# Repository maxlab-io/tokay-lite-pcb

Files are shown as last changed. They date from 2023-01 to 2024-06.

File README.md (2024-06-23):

# Tokay Lite: Low Power ESP32 Edge AI Camera (https://maxlab.io/store/edge-ai-camera/)

[Tokay Lite](https://maxlab.io/store/edge-ai-camera/) is the ESP32 camera development board ideal for low-power image
processing applications on the edge.

Tokay Lite can be used as standalone devkit to aid developers with a convinient
tool or be embedded in the bigger system to augument it with the vision and
image processing data.

## Tokay Lite Features

* ESP32-S3 chip compatible with TensorFlow Lite, enabling AI right in the device.
* OV2640 camera sensor delivering 15 fps @ 2MP.
* Ultra-low power design: programmable external RTC controls
  the entire power distribution, allowing the device to consume microamps during
  sleep.
* Motion detection with wake-up support.
* Nightvision mode with software-controlled IR filter to improve
  pictures during daytime.
* 10 IR LEDs to illuminate the scene.
* Ambient light sensor to intelligently select between day and night-time modes.
* Convenient 70mm x 70mm form factor.
* Embedded lithium battery charger and JST-PH battery connector.

## PCB Dimensions

Tokay LITE is packed into 70x70mm with M3 mounting holes at each corner,
as can be seen from a following drawing:

Tokay AI Camera dimensions

## Firmware

The Tokay AI Camera is powered by the ESP-IDF framework.

Check the [GitHub firmware repository]() for the source code
or [the camera documentation page](https://docs.maxlab.io/docs/edge-ai-tokay-lite/firmware/)
for more information on how to build an flash the firmware.

## KiCAD Dependencies

The Tokay PCB is made using [KiML](https://github.com/maxlab-io/kiml/),
the atomic components library from MAXLAB.

If you wish to modify the schematics or PCB you need to install KiML first.
Proceed to [the KiML installation guide](https://github.com/maxlab-io/kiml#how-to-install-kiml)
for further information.

## Ordering Samples

For information about ordering samples please proceed to [MAXLAB Tokay Lite product page](https://maxlab.io/store/edge-ai-camera/).

## License

The project is licensed under [the CERN Open Hardware Licence Version 2 - Permissive](./LICENSE.txt) terms.

## Business Inquiries or Questions

If you have the camera-related questions or inquiries, please drop us an email
on [hi@maxlab.io](mailto:hi@maxlab.io) or send us a message trough
[the Contact Us form](https://maxlab.io/contact/).

## Other Links

* [CADLAB.io](https://cadlab.io/project/27230). 
* [Hackaday](https://hackaday.io/project/189135-tokay-lite-multi-purpose-esp32-ai-camera)

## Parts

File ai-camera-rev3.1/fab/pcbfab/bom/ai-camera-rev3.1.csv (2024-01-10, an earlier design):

Item | Qty | Reference(s) | Value | LibPart | Footprint | Datasheet | DNP | DCR | LNK1 | LNK2 | MFR | MPN | Pmax | Rating | SNB1 | SNB2 | SPL1 | SPL2 | SPN1 | SPN2 | TCR | Tolerance | Type | UserValue
1 | 7 | C1, C11, C12, C25, C38, C39, C40 | 100u_CASE-B-3528_TAJB107K006RNJ | 00-kiml-capacitors-smd:100u_CASE-B-3528_TAJB107K006RNJ | 00-kiml-capacitor-tantalum:CP_EIA-3528-15_AVX-H | https://datasheet.lcsc.com/lcsc/2111161030_Kyocera-AVX-TAJB107K006RNJ-_C16133.pdf |  |  | https://jlcpcb.com/partdetail/KyoceraAvx-TAJB107K006RNJ/C16133 |  | Kyocera AVX | TAJB107K006RNJ |  | 6.3V | Basic Part |  | JLCPCB |  | C16133 |  |  | 10% |  | 100u
2 | 48 | C2, C3, C4, C5, C6, C7, C8, C9, C10, C13, C14, C15, C16, C18, C19, C20, C21, C22, C23, C24, C26, C27, C28, C29, C30, C31, C32, C33, C34, C35, C36, C37, C41, C42, C43, C44, C45, C46, C47, C49, C50, C51, C52, C53, C54, C55, C56, C57 | 10u_0402_CL05A105KA5NQNC | 00-kiml-capacitors-smd:1u_0402_CL05A105KA5NQNC | Capacitor_SMD:C_0402_1005Metric | https://datasheet.lcsc.com/lcsc/1811091611_Samsung-Electro-Mechanics-CL05A105KA5NQNC_C52923.pdf |  |  | https://jlcpcb.com/partdetail/53938-CL05A105KA5NQNC/C52923 |  | Samsung | CL05A105KA5NQNC |  | 25V | Basic Part |  | JLCPCB |  | C52923 |  |  | 10% |  | 1u
3 | 2 | C17, C48 | 22p_0402_0402CG220J500NT | 00-kiml-capacitors-smd:22p_0402_0402CG220J500NT | Capacitor_SMD:C_0402_1005Metric | https://datasheet.lcsc.com/lcsc/1811141710_FH--Guangdong-Fenghua-Advanced-Tech-0402CG220J500NT_C1555.pdf |  |  | https://jlcpcb.com/partdetail/1907-0402CG220J500NT/C1555 |  | FH | 0402CG220J500NT |  | 50V | Basic part |  | JLCPCB |  | C1555 |  |  | 5% | C0G | 22p
4 | 2 | D1, D7 | 0603_RED_KT-0603R | 00-kiml-led-smd:0603_RED_KT-0603R | LED_SMD:LED_0603_1608Metric | https://datasheet.lcsc.com/lcsc/1810231112_Hubei-KENTO-Elec-KT-0603R_C2286.pdf |  |  | https://jlcpcb.com/partdetail/Hubei_KentoElec-KT0603R/C2286 |  | Hubei KENTO | KT-0603R |  |  | Basic part |  | JLCPCB |  | C2286 |  |  |  |  | ~{CHRG}
5 | 1 | D2 | 0603_GREEN_19-217/GHC-YR1S2/3T | 00-kiml-led-smd:0603_GREEN_19-217/GHC-YR1S2/3T | LED_SMD:LED_0603_1608Metric |  |  |  | https://jlcpcb.com/partdetail/EverlightElec-19_217_GHC_YR1S23T/C72043 |  | Everlight | 19-217/GHC-YR1S2/3T |  |  | Basic part |  | JLCPCB |  | C72043 |  |  |  |  | ~{STDBY}
6 | 3 | D3, D4, D5 | SOD-523_BSD5C051L | 00-kiml-power-protection:SOD-523_BSD5C051L | Diode_SMD:D_SOD-523 | https://datasheet.lcsc.com/lcsc/1810161421_BORN-BSD5C051L_C151983.pdf |  |  | https://jlcpcb.com/partdetail/Born-BSD5C051L/C151983 |  | BORN | BSD5C051L |  |  | Extended Part |  | JLCPCB |  | C151983 |  |  |  |  | TVS 5V
7 | 2 | D6, D8 | B5819W-SL_SOD-123 | 00-kiml-diode:B5819W-SL_SOD-123 | Diode_SMD:D_SOD-123 | https://datasheet.lcsc.com/lcsc/1809140216_Jiangsu-Changjing-Electronics-Technology-Co---Ltd--B5819W-SL_C8598.pdf |  |  | https://jlcpcb.com/partdetail/9093-B5819WSL/C8598 |  | Jiangsu Changjing Electronics Technology | B5819W SL |  | 1A | Basic Part |  | JLCPCB |  | C8598 |  |  |  |  | D
8 | 10 | D9, D10, D11, D12, D13, D14, D15, D16, D17, D18 | 0603_IR_850nm_E6C0603IRAC1UDA | 00-kiml-led-smd:0603_IR_850nm_E6C0603IRAC1UDA | LED_SMD:LED_0603_1608Metric | https://datasheet.lcsc.com/lcsc/1912111437_EKINGLUX-E6C0603IRAC1UDA-850nm_C396643.pdf |  |  | https://jlcpcb.com/partdetail/Ekinglux-E6C0603IRAC1UDA_850nm/C396643 |  | EKINGLUX | E6C0603IRAC1UDA |  |  | Extended Part |  | JLCPCB |  | C396643 |  |  |  |  | LED_IR
9 | 4 | H1, H2, H3, H4 | MountingHole_Pad | Mechanical:MountingHole_Pad | MountingHole:MountingHole_3.2mm_M3_Pad_TopBottom | ~
10 | 1 | J1 | Conn-01x02_P2mm_NONAME_JST-PH_C47647 | 00-kiml-connector-jst:Conn-01x02_P2mm_NONAME_JST-PH_C47647 | 00-kiml-connector-jst:JST_PH_S2B-PH-SM4-TB_1x02-1MP_P2.00mm_Horizontal | https://datasheet.lcsc.com/lcsc/1912111436_BOOMELE-Boom-Precision-Elec-C47647_C47647.pdf |  |  | https://jlcpcb.com/partdetail/boomele_boom_Precision_elec-C47647/C47647 |  | BOOMELE | C47647 |  |  | Extended Part |  | JLCPCB |  | C47647 |  |  |  |  | BATT
11 | 1 | J2 | TYPE-C-31-M-12 | 00-kiml-connector-usb:USB_C_Receptacle_USB2.0_TYPE-C-31-M-12 | 00-kiml-connector-usb:USB_C_Receptacle_HRO_TYPE-C-31-M-12 | https://datasheet.lcsc.com/lcsc/2205251630_Korean-Hroparts-Elec-TYPE-C-31-M-12_C165948.pdf |  |  | https://jlcpcb.com/partdetail/Korean_HropartsElec-TYPE_C_31_M12/C165948 |  | Korean Hroparts | TYPE-C-31-M-12 |  |  | Extended Part |  | JLCPCB |  | C165948 |  |  |  |  | USB-C
12 | 1 | J4 | Conn-02x10_P2.54mm_B-2100S20P-B110 | 00-kiml-connector:Conn-02x10_P2.54mm_B-2100S20P-B110 | Connector_PinHeader_2.54mm:PinHeader_2x10_P2.54mm_Vertical | https://datasheet.lcsc.com/lcsc/1810241611_Ckmtw-Shenzhen-Cankemeng-B-2100S20P-B110_C124359.pdf |  |  | https://jlcpcb.com/partdetail/125634-B_2100S20PB110/C124359 |  | Ckmtw | B-2100S20P-B110 |  |  |  |  | JLCPCB |  | C124359 |  |  |  |  | USR_EXT
13 | 1 | J5 | Conn-01x02_P1.25mm_10114829-10102LF | 00-kiml-connector:Conn-01x02_P1.25mm_10114829-10102LF | 00-kiml-connector-amphenol:10114829-10102LF | https://datasheet.lcsc.com/lcsc/1811011512_Amphenol-ICC-10114829-10102LF_C239062.pdf |  |  | https://www.digikey.com/en/products/detail/amphenol-icc-fci/10114829-10102LF/2658929 | https://jlcpcb.com/partdetail/AmphenolIcc-1011482910102LF/C239062 | Amphenol ICC (FCI) | 10114829-10102LF |  |  |  | Extended Part | Digikey | JLCPCB | 609-4383-2-ND | C239062 |  |  |  | IRCUT
14 | 1 | J6 | Conn_01x24_FFC_0.5mm_AFC01-S24FCC-00 | 00-kiml-connector-fpc-ffc:Conn_01x24_FFC_0.5mm_AFC01-S24FCC-00 | 00-kiml-connector-fpc-ffc:Jushuo_AFC01-S24FCC-00_1x24-1MP_P0.50_Horizontal | https://datasheet.lcsc.com/lcsc/1811021338_JUSHUO-AFC01-S24FCC-00_C262276.pdf |  |  | https://jlcpcb.com/partdetail/Jushuo-AFC01_S24FCC00/C262276 |  | JUSHUO | AFC01-S24FCC-00 |  |  | Extended Part |  | JLCPCB |  | C262276 |  |  |  |  | CAMERA
15 | 1 | JP1 | USB_PWR | Jumper:SolderJumper_2_Bridged | Jumper:SolderJumper-2_P1.3mm_Bridged2Bar_Pad1.0x1.5mm | ~
16 | 1 | JP2 | PIR | Jumper:SolderJumper_2_Bridged | Jumper:SolderJumper-2_P1.3mm_Bridged2Bar_Pad1.0x1.5mm | ~
17 | 3 | L1, L2, L4 | FB_2A_0805_220R@100MHz_BLM21PG221SN1D | 00-kiml-inductors:FB_2A_0805_220R@100MHz_BLM21PG221SN1D | Inductor_SMD:L_0805_2012Metric_Pad1.15x1.40mm_HandSolder | ~ |  |  | https://jlcpcb.com/partdetail/MurataElectronics-BLM21PG221SN1D/C85840 |  | Murata Electronics | BLM21PG221SN1D |  | 2A |  |  | JLCPCB |  | C85840 |  |  |  |  | FB
18 | 2 | L3, L5 | 10u_1.5A_4x4mm_SWPA4030S100MT | 00-kiml-inductors:10u_1.5A_4x4mm_SWPA4030S100MT | 00-kiml-inductor-smd:L_Sunlord_SWPA40xxS | https://datasheet.lcsc.com/lcsc/2110091630_Sunlord-SWPA4030S100MT_C38117.pdf |  | 130m | https://jlcpcb.com/partdetail/Sunlord-SWPA4030S100MT/C38117 |  | Sunlord | SWPA4030S100MT |  | 1.5A |  |  | JLCPCB |  | C38117 |  |  |  |  | 10u
19 | 6 | Q1, Q2, Q5, Q7, Q9, Q10 | 2N7002 | 00-kiml-transistor-fet:2N7002 | Package_TO_SOT_SMD:SOT-23 | https://datasheet.lcsc.com/lcsc/1810151612_Jiangsu-Changjing-Electronics-Technology-Co---Ltd--2N7002_C8545.pdf |  |  | https://jlcpcb.com/partdetail/9040-2N7002/C8545 |  | JCET | 2N7002 |  |  | Basic Part |  | JLCPCB |  | C8545 |  |  |  |  | 2N7002
20 | 4 | Q3, Q4, Q6, Q8 | AO3401A | 00-kiml-transistor-fet:AO3401A | Package_TO_SOT_SMD:SOT-23 | https://datasheet.lcsc.com/lcsc/1810171817_Alpha---Omega-Semicon-AO3401A_C15127.pdf |  |  | https://lcsc.com/product-detail/MOSFETs_Alpha-Omega-Semicon-AO3401A_C15127.html | https://jlcpcb.com/partdetail/Alpha_OmegaSemicon-AO3401A/C15127 | Alpha & Omega Semiconductor Inc. | AO3401A |  |  |  | Basic Part | LCSC | JLCPCB | C15127 | C15127 |  |  |  | AO3401A
21 | 3 | R1, R2, R23 | 976k_0402_0402WGD9763TCE | 00-kiml-resistors-smd:976k_0402_0402WGD9763TCE | Resistor_SMD:R_0402_1005Metric | https://datasheet.lcsc.com/lcsc/2205312216_UNI-ROYAL-Uniroyal-Elec-0402WGD9763TCE_C423262.pdf |  |  | https://jlcpcb.com/partdetail/416212-0402WGD9763TCE/C423262 |  | UNI-ROYAL | 0402WGD9763TCE |  |  | Extended Part |  | JLCPCB |  | C423262 |  |  | 0.5% |  | 976k
22 | 13 | R3, R13, R15, R16, R17, R18, R19, R21, R22, R24, R25, R31, R32 | 215k_0402_0402WGD2153TCE | 00-kiml-resistors-smd:215k_0402_0402WGD2153TCE | Resistor_SMD:R_0402_1005Metric | https://datasheet.lcsc.com/lcsc/2205312216_UNI-ROYAL-Uniroyal-Elec-0402WGD2153TCE_C423299.pdf |  |  | https://jlcpcb.com/partdetail/416249-0402WGD2153TCE/C423299 |  | UNI-ROYAL | 0402WGD2153TCE |  |  | Extended Part |  | JLCPCB |  | C423299 |  |  | 0.5% |  | 215k
23 | 3 | R4, R5, R28 | 1k_0402_0402WGF1001TCE | 00-kiml-resistors-smd:1k_0402_0402WGF1001TCE | Resistor_SMD:R_0402_1005Metric | https://datasheet.lcsc.com/lcsc/2206010216_UNI-ROYAL-Uniroyal-Elec-0402WGF1001TCE_C11702.pdf |  |  | https://jlcpcb.com/partdetail/12256-0402WGF1001TCE/C11702 |  | UNI-ROYAL | 0402WGF1001TCE | 62.5mW |  | Basic part |  | JLCPCB |  | C11702 |  |  | 1% |  | 1k
24 | 11 | R6, R7, R10, R11, R12, R14, R20, R26, R27, R29, R30 | 10k_0402_0402WGF1002TCE | 00-kiml-resistors-smd:10k_0402_0402WGF1002TCE | Resistor_SMD:R_0402_1005Metric | https://datasheet.lcsc.com/lcsc/2206010100_UNI-ROYAL-Uniroyal-Elec-0402WGF1002TCE_C25744.pdf |  |  | https://jlcpcb.com/partdetail/26487-0402WGF1002TCE/C25744 |  | UNI-ROYAL | 0402WGF1002TCE | 62.5mW |  | Basic part |  | JLCPCB |  | C25744 |  | 100ppm | 1% |  | 10k
25 | 2 | R8, R9 | 5.1k_0603_0603WAF5101T5E | 00-kiml-resistors-smd:5.1k_0603_0603WAF5101T5E | Resistor_SMD:R_0603_1608Metric | https://datasheet.lcsc.com/lcsc/2206010116_UNI-ROYAL-Uniroyal-Elec-0603WAF5101T5E_C23186.pdf |  |  | https://jlcpcb.com/partdetail/23913-0603WAF5101T5E/C23186 |  | UNI-ROYAL | 0603WAF5101T5E |  |  | Basic Part |  | JLCPCB |  | C23186 |  |  | 1% |  | 5.1k
26 | 1 | R33 | 2.43R_0805_0805W8F243KT5E | 00-kiml-resistors-smd:2.43R_0805_0805W8F243KT5E | Resistor_SMD:R_0805_2012Metric | https://datasheet.lcsc.com/lcsc/2205311916_UNI-ROYAL-Uniroyal-Elec-0805W8F243KT5E_C247100.pdf |  |  | https://jlcpcb.com/partdetail/244308-0805W8F243KT5E/C247100 |  | UNI-ROYAL | 0805W8F243KT5E |  |  | Extended Part |  | JLCPCB |  | C247100 |  |  | 1% |  | 2.43R
27 | 2 | SW1, SW4 | SW_PB_90deg_K2-1102AQ-H4CW-01 | 00-kiml-switch-button-tht:SW_PB_90deg_K2-1102AQ-N4CW-01 | 00-kiml-switch-button-tht:SW_PB_90deg_K2-1102AQ-H4CW-01 | https://datasheet.lcsc.com/lcsc/2012052036_Korean-Hroparts-Elec-K2-1102AQ-H4CW-01_C961738.pdf |  |  | https://jlcpcb.com/partdetail/1041843-K2_1102AQ_H4CW01/C961738 |  | Korean Hroparts | K2-1102AQ-N4CW-01 |  |  | Extended Part |  | JLCPCB |  | C338650 |  |  |  |  | PWR_ON
28 | 2 | SW2, SW3 | SW_PB_TS-1187A-B-A-B | 00-kiml-switch-button-smd:SW_PB_TS-1187A-B-A-B | Button_Switch_SMD:SW_SPST_TL3342 | https://datasheet.lcsc.com/lcsc/2002271431_XKB-Connectivity-TS-1187A-B-A-B_C318884.pdf |  |  | https://jlcpcb.com/partdetail/XkbConnectivity-TS_1187A_B_AB/C318884 |  | XKB Connectivity | TS-1187A-B-A-B |  |  | Basic Part |  | JLCPCB |  | C318884 |  |  |  |  | BOOT
29 | 24 | TP1, TP2, TP3, TP4, TP5, TP6, TP7, TP8, TP9, TP10, TP11, TP12, TP13, TP14, TP15, TP16, TP17, TP18, TP19, TP20, TP21, TP22, TP23, TP24 | TestPoint | Connector:TestPoint | TestPoint:TestPoint_Pad_D1.0mm | ~
30 | 1 | U1 | TP4057-42-SOT26-R | 00-kiml-battery-management:TP4057-42-SOT26-R | Package_TO_SOT_SMD:SOT-23-6 | https://datasheet.lcsc.com/lcsc/1811021622_TOPPOWER-Nanjing-Extension-Microelectronics-TP4057-42-SOT26-R_C12044.pdf |  |  | https://jlcpcb.com/partdetail/12599-TP4057_42_SOT26R/C12044 |  | TOPPOWER | TP4057-42-SOT26-R |  |  | Basic Part |  | JLCPCB |  | C12044 |  |  |  |  | TP4057
31 | 2 | U2, U7 | XC6206-2.8V | 00-kiml-regulator-linear:XC6206-2.8V | Package_TO_SOT_SMD:SOT-23 | https://datasheet.lcsc.com/lcsc/2109071530_YONGYUTAI-XC6206-2-8V_C2892669.pdf |  |  | https://jlcpcb.com/partdetail/Yongyutai-XC6206_28V/C2892669 |  | YONGYUTAI | XC6206-2.8V |  |  | Extended Part |  | JLCPCB |  | C2892669 |  |  |  |  | XC6206-2.8V
32 | 1 | U3 | PCF85063AT | 00-kiml-timer-rtc:PCF85063AT/AAZ | Package_SO:SO-8_3.9x4.9mm_P1.27mm | https://www.nxp.com/docs/en/data-sheet/PCF85063A.pdf |  |  | https://jlcpcb.com/partdetail/NxpSemicon-PCF85063ATAAZ/C2157792 |  | NXP Semiconductors | PCF85063AT/AAZ |  |  | Extended Part |  | JLCPCB |  | C2157792 |  |  |  |  | PCF85063A
33 | 1 | U4 | TI_SN74LVC1G373DBVR | 00-kiml-74xGxx:TI_SN74LVC1G373DBVR | Package_TO_SOT_SMD:SOT-23-6 | https://www.ti.com/cn/lit/ds/symlink/sn74lvc1g373.pdf |  |  | https://jlcpcb.com/partdetail/TexasInstruments-SN74LVC1G373DBVR/C128413 |  | Texas Instruments | SN74LVC1G373DBVR |  |  | Extended Part |  | JLCPCB |  | C128413 |  |  |  |  | D-LATCH
34 | 1 | U5 | SY8089AAAC | 00-kiml-regulator-switching:SY8089AAAC | Package_TO_SOT_SMD:SOT-23-5 | https://datasheet.lcsc.com/lcsc/2108261630_Silergy-Corp-SY8089AAAC_C78988.pdf |  |  | https://jlcpcb.com/partdetail/SilergyCorp-SY8089AAAC/C78988 |  | Silergy | SY8089AAAC |  |  | Extended Part |  | JLCPCB |  | C78988 |  |  |  |  | SY8089AAAC
35 | 1 | U6 | PIR_AS312 | 00-kiml-optical:PIR_AS312 | 00-kiml-optical:AS312 | https://datasheet.lcsc.com/lcsc/2004261131_Senba-Sensing-Tech-AS312_C90465.pdf |  |  | https://jlcpcb.com/partdetail/Senba_SensingTech-AS312/C90465 |  | Senba Sensing | AS312 |  |  | Extended Part |  | JLCPCB |  | C90465 |  |  |  |  | AS312
36 | 1 | U8 | RT9166-12GVL | 00-kiml-regulator-linear:RT9166-12GVL | Package_TO_SOT_SMD:SOT-23 | https://datasheet.lcsc.com/lcsc/1810312311_Richtek-Tech-RT9166-12GVL_C29175.pdf |  |  | https://jlcpcb.com/partdetail/RichtekTech-RT916612GVL/C29175 |  | Richtek Tech | RT9166-12GVL |  |  | Extended Part |  | JLCPCB |  | C29175 |  |  |  |  | RT9166-12GVL
37 | 1 | U9 | AP1511B | 00-kiml-ircut-driver:AP1511B | Package_TO_SOT_SMD:SOT-23-6 | https://datasheet.lcsc.com/lcsc/2208021730_UMW-Youtai-Semiconductor-Co---Ltd--AP1511B_C347457.pdf |  |  | https://lcsc.com/product-detail/Motor-Driver-ICs_UMW-Youtai-Semiconductor-Co-Ltd-AP1511B_C347457.html | https://jlcpcb.com/partdetail/324117-AP1511B/C347457 | UMW | AP1511B |  |  |  | Extended Part | LCSC | JLCPCB | C347457 | C347457 |  |  |  | AP1511B
38 | 1 | U10 | ESP32-S3-WROOM-1-N16R8 | 00-kiml-rf-module:ESP32-S3-WROOM-1-N16R8 | 00-kiml-rf-module:ESP32-S3-WROOM-1 | https://www.espressif.com/sites/default/files/documentation/esp32-s3-wroom-1_wroom-1u_datasheet_en.pdf |  |  | https://www.lcsc.com/product-detail/WiFi-Modules_Espressif-Systems-ESP32-S3-WROOM-1-N16R8_C2913202.html | https://jlcpcb.com/partdetail/3198300-ESP32_S3_WROOM_1N16R8/C2913202 | Espressif | ESP32-S3-WROOM-1-N16R8 |  |  |  | Extended part | LCSC | JLCPCB | C2913202 | C2913202 |  |  |  | ESP32-S3-WROOM-1
39 | 1 | U11 | MT9284-28J | 00-kiml-driver-led:MT9284-28J | Package_TO_SOT_SMD:SOT-23-6 | https://datasheet.lcsc.com/lcsc/1806041028_XI-AN-Aerosemi-Tech-MT9284-28J_C181780.pdf |  |  | https://jlcpcb.com/partdetail/xi_an_AerosemiTech-MT928428J/C181780 |  | AEROSEMI | MT9284-28J |  |  | Extended Part |  | JLCPCB |  | C181780 |  |  |  |  | MT9284-28J
40 | 1 | U12 | LTR-303ALS-01 | 00-kiml-optical:LTR-303ALS-01 | 00-kiml-optical:Lite-On_LTR-303ALS-01 | https://datasheet.lcsc.com/lcsc/1912111437_Lite-On-LTR-303ALS-01_C364577.pdf |  |  | https://www.lcsc.com/product-detail/Ambient-Light-Sensors_Lite-On-LTR-303ALS-01_C364577.html |  | Lite-On | LTR-303ALS-01 |  |  | Extended Part |  | JLCPCB |  | C364577 |  |  |  |  | LTR-303ALS-01
41 | 1 | Y1 | 32.768kHz_Q13FC1350000400 | 00-kiml-crystal:32.768kHz_Q13FC1350000400 | 00-kiml-crystal-smd:Crystal_SMD_3215-2Pin_3.2x1.5mm | https://datasheet.lcsc.com/lcsc/1810171817_Seiko-Epson-Q13FC1350000400_C32346.pdf |  |  | https://jlcpcb.com/partdetail/SeikoEpson-Q13FC1350000400/C32346 |  | Seiko Epson | Q13FC1350000400 |  |  | Basic Part |  | JLCPCB |  | C32346 |  |  |  |  | 32.768kHz

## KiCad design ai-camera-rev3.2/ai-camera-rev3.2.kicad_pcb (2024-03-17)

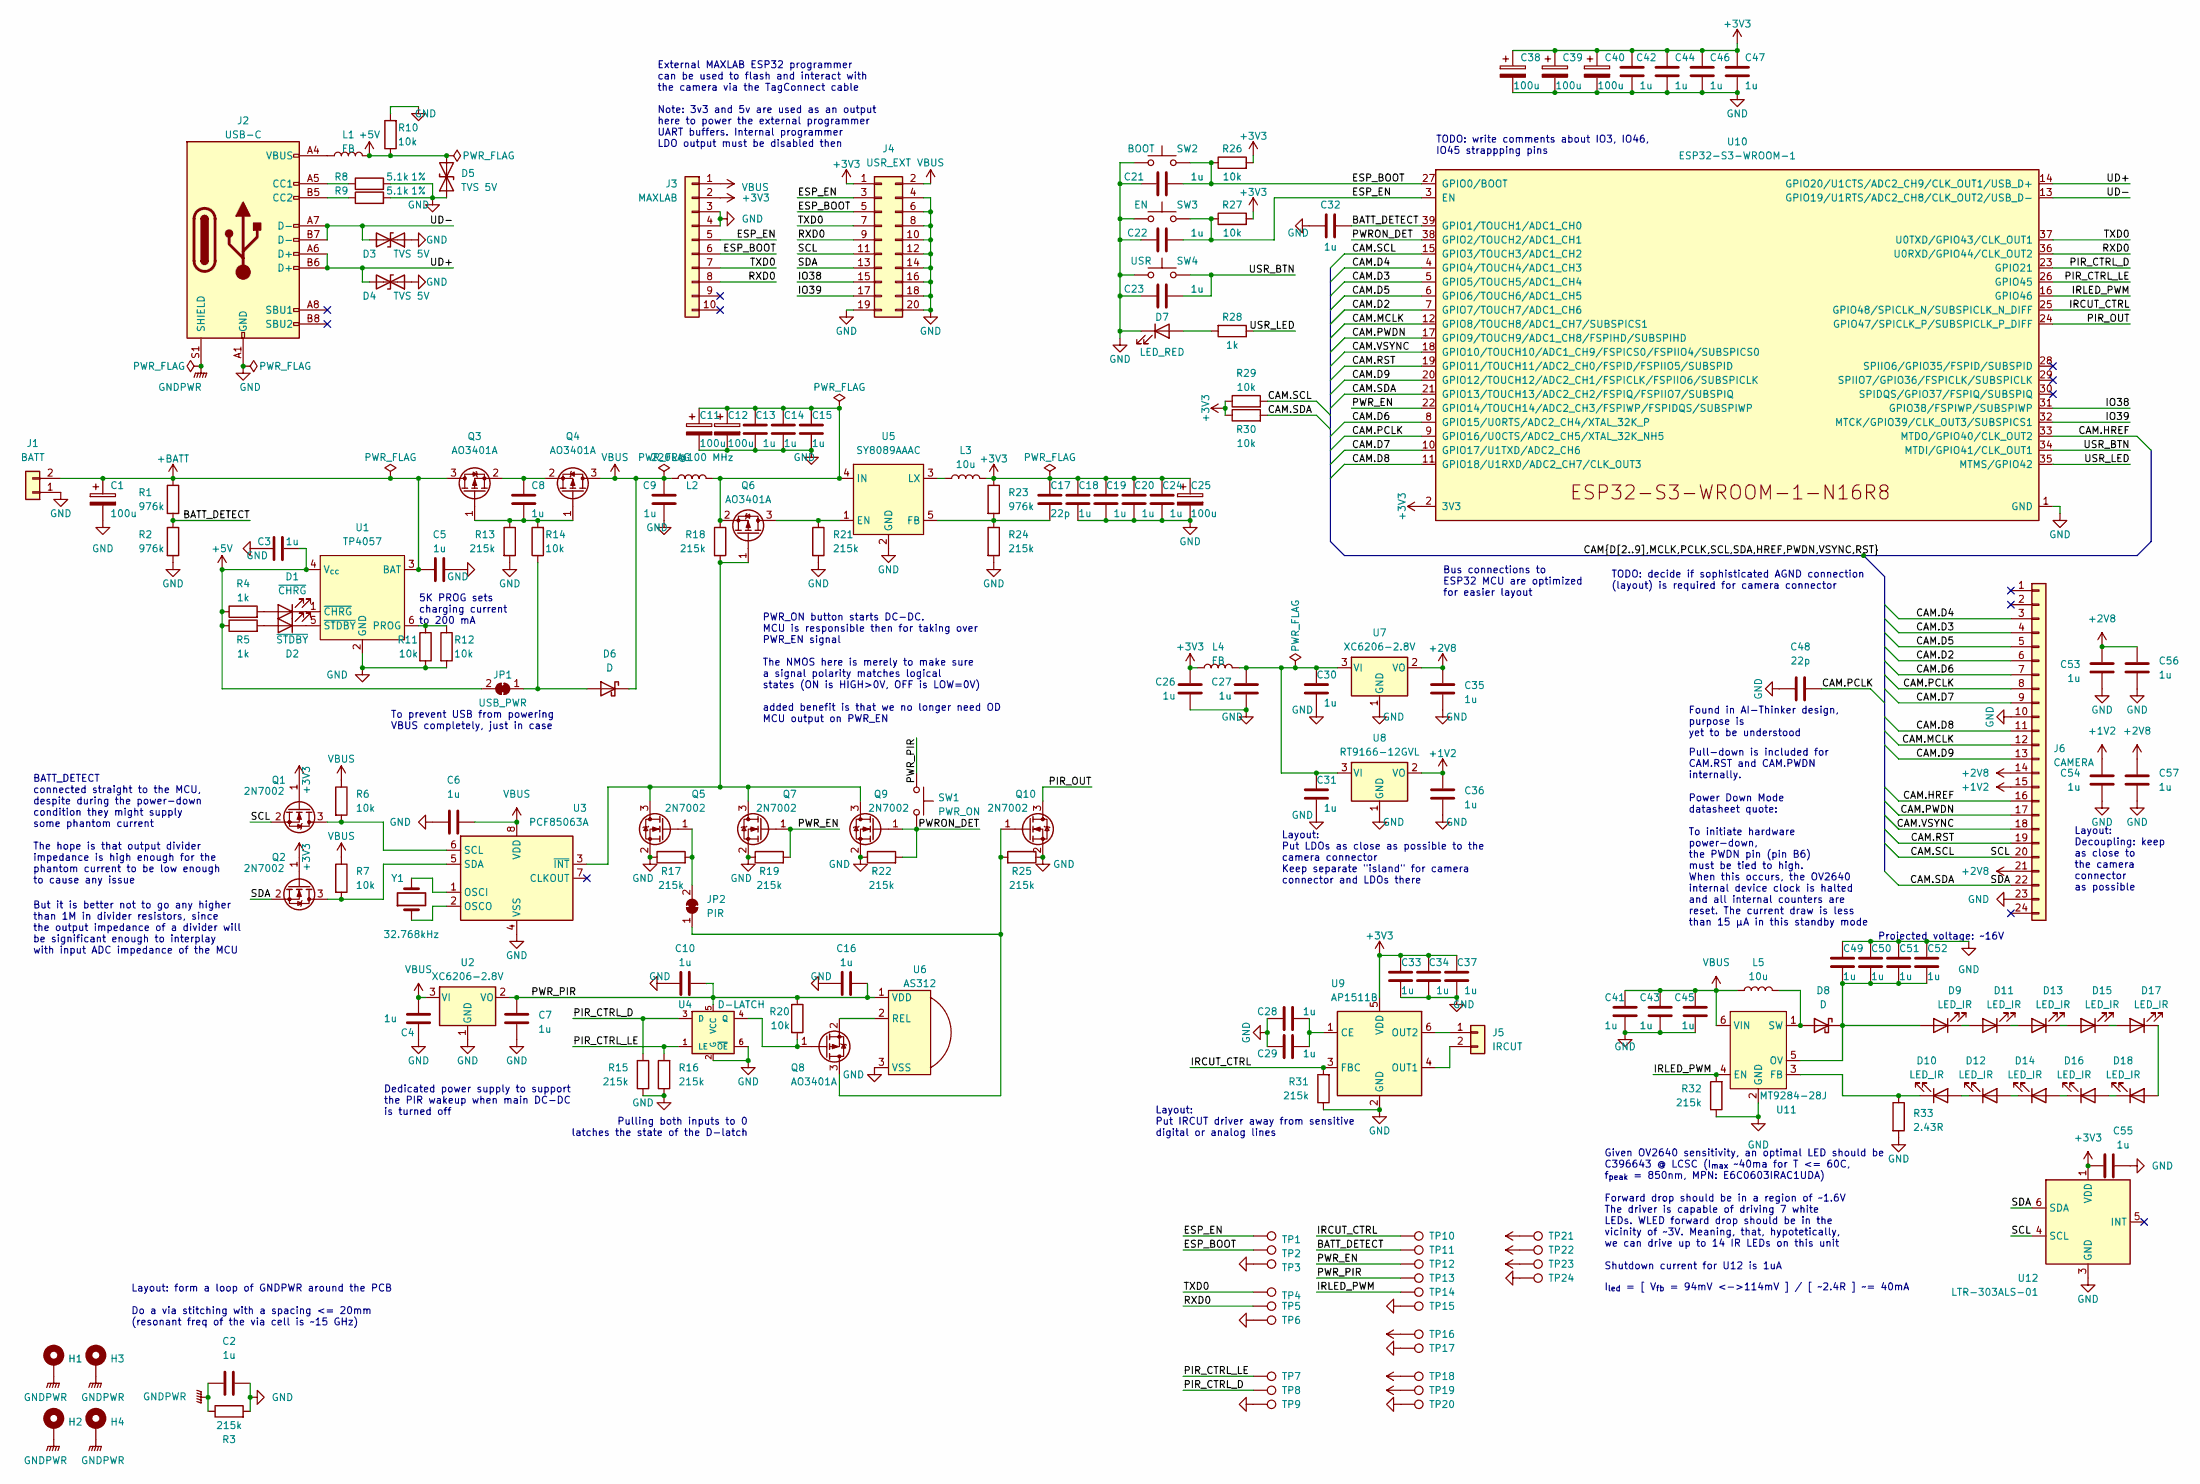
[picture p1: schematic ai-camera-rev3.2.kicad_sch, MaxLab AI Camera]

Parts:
C1, C11, C12, C25, C38, C39, C40: 100u_CASE-B-3528_TAJB107K006RNJ; CP_EIA-3528-15_AVX-H; Rating 6.3V; Tolerance 10%; MPN TAJB107K006RNJ
C2, C6, C10, C15, C16, C18, C21, C23, C28, C29, C32, C33, C45, C46, C47, C49, C54, C55, C56, C57: 10u_0402_CL05A105KA5NQNC; C_0402_1005Metric; Tolerance 10%; Rating 25V; MPN CL05A105KA5NQNC
C3, C4, C5, C7, C8, C9, C13, C14, C19, C20, C22, C24, C26, C27, C30, C31, C34, C35, C36, C37, C41, C42, C43, C44, C50, C51, C52, C53: 10u_0402_CL05A105KA5NQNC; C_0402_1005Metric; Rating 25V; Tolerance 10%; MPN CL05A105KA5NQNC
C17, C48: 22p_0402_0402CG220J500NT; C_0402_1005Metric; Rating 50V; Tolerance 5%; MPN 0402CG220J500NT
D1, D7: 0603_RED_KT-0603R; LED_0603_1608Metric; MPN KT-0603R
D2: 0603_GREEN_19-217/GHC-YR1S2/3T; LED_0603_1608Metric; MPN 19-217/GHC-YR1S2/3T
D3, D4, D5: SOD-523_BSD5C051L; D_SOD-523; MPN BSD5C051L
D6, D8: B5819W-SL_SOD-123; D_SOD-123; Rating 1A; MPN B5819W SL
D9, D10, D11, D12, D13, D14, D15, D16, D17, D18: 0603_IR_850nm_E6C0603IRAC1UDA; LED_0603_1608Metric; MPN E6C0603IRAC1UDA
H1, H2, H3, H4: MountingHole_Pad; MountingHole_3.2mm_M3_Pad_TopBottom
J1: Conn-01x02_P2mm_NONAME_JST-PH_C47647; JST_PH_S2B-PH-SM4-TB_1x02-1MP_P2.00mm_Horizontal; MPN C47647
J2: TYPE-C-31-M-12; USB_C_Receptacle_HRO_TYPE-C-31-M-12; MPN TYPE-C-31-M-12
J3: MAXLAB; Tag-Connect_TC2050-IDC-FP_2x05_P1.27mm_Vertical
J4: Conn-02x10_P2.54mm_B-2100S20P-B110; PinHeader_2x10_P2.54mm_Vertical; MPN B-2100S20P-B110
J5: Conn-01x02_P1.25mm_10114829-10102LF; 10114829-10102LF; MPN 10114829-10102LF
J6: Conn_01x24_FFC_0.5mm_AFC01-S24FCC-00; Jushuo_AFC01-S24FCC-00_1x24-1MP_P0.50_Horizontal; MPN AFC01-S24FCC-00
JP1: USB_PWR; SolderJumper-2_P1.3mm_Bridged2Bar_Pad1.0x1.5mm
JP2: PIR; SolderJumper-2_P1.3mm_Bridged2Bar_Pad1.0x1.5mm
L1, L2, L4: FB_2A_0805_220R@100MHz_BLM21PG221SN1D; L_0805_2012Metric_Pad1.15x1.40mm_HandSolder; Rating 2A; MPN BLM21PG221SN1D
L3, L5: 10u_1.5A_4x4mm_SWPA4030S100MT; L_Sunlord_SWPA40xxS; Rating 1.5A; MPN SWPA4030S100MT
Q1, Q2, Q5, Q7, Q9, Q10: 2N7002; SOT-23; MPN 2N7002
Q3, Q4, Q6, Q8: AO3401A; SOT-23; MPN AO3401A
R1, R2, R23: 976k_0402_0402WGD9763TCE; R_0402_1005Metric; Tolerance 0.5%; MPN 0402WGD9763TCE
R3, R13, R15, R16, R17, R18, R19, R21, R22, R24, R25, R31, R32: 215k_0402_0402WGD2153TCE; R_0402_1005Metric; Tolerance 0.5%; MPN 0402WGD2153TCE
R4, R5, R28: 1k_0402_0402WGF1001TCE; R_0402_1005Metric; Tolerance 1%; MPN 0402WGF1001TCE
R6, R7, R10, R11, R12, R14, R20, R26, R27, R29, R30: 10k_0402_0402WGF1002TCE; R_0402_1005Metric; Tolerance 1%; MPN 0402WGF1002TCE
R8, R9: 5.1k_0603_0603WAF5101T5E; R_0603_1608Metric; Tolerance 1%; MPN 0603WAF5101T5E
R33: 2.43R_0805_0805W8F243KT5E; R_0805_2012Metric; Tolerance 1%; MPN 0805W8F243KT5E
SW1, SW4: SW_PB_90deg_K2-1102AQ-H4CW-01; MPN K2-1102AQ-N4CW-01
SW2, SW3: SW_PB_TS-1187A-B-A-B; SW_SPST_TL3342; MPN TS-1187A-B-A-B
TP1, TP2, TP3, TP4, TP5, TP6, TP7, TP8, TP9, TP10, TP11, TP12, TP13, TP14, TP15, TP16, TP17, TP18, TP19, TP20, TP21, TP22, TP23, TP24: TestPoint; TestPoint_Pad_D1.0mm
U1: TP4057-42-SOT26-R; SOT-23-6; MPN TP4057-42-SOT26-R
U2, U7: XC6206-2.8V; SOT-23; MPN XC6206-2.8V
U3: PCF85063AT; SO-8_3.9x4.9mm_P1.27mm; MPN PCF85063AT/AAZ
U4: TI_SN74LVC1G373DBVR; SOT-23-6; MPN SN74LVC1G373DBVR
U5: SY8089AAAC; SOT-23-5; MPN SY8089AAAC
U6: PIR_AS312; AS312; MPN AS312
U8: RT9166-12GVL; SOT-23; MPN RT9166-12GVL
U9: AP1511B; SOT-23-6; MPN AP1511B
U10: ESP32-S3-WROOM-1-N16R8; ESP32-S3-WROOM-1; MPN ESP32-S3-WROOM-1-N16R8
U11: MT9284-28J; SOT-23-6; MPN MT9284-28J
U12: LTR-303ALS-01; Lite-On_LTR-303ALS-01; MPN LTR-303ALS-01
Y1: 32.768kHz_Q13FC1350000400; Crystal_SMD_3215-2Pin_3.2x1.5mm; MPN Q13FC1350000400

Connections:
+1V2: C36.1, C54.2, J6.15, TP16.1, U8.2 (VO)
+2V8: C35.1, C53.1, C56.2, C57.2, J6.14, J6.21, TP18.1, U7.2 (VO)
+3V3: C17.1, C18.2, C19.2, C20.2, C24.2, C25.1, C26.1, C33.2, C34.2, C37.2, C38.1, C39.1, C40.1, C42.1, C44.1, C46.1, C47.1, C55.1, J3.2, J4.1, L3.2, L4.1, Q1.1 (G), Q2.1 (G), R23.1, R26.2, R27.2, R29.1, R30.1, TP22.1, U9.5 (VDD), U10.2 (3V3), U12.1 (VDD)
+5V: C3.2, D5.2 (A2), JP1.2 (B), L1.2, R4.1, R5.1, R10.1, TP23.1, U1.4 (V_{cc})
+BATT: C1.1, C5.1, J1.2, Q3.3 (D), R1.1, TP19.1, U1.3 (BAT)
/BATT_DETECT: C32.1, R1.2, R2.1, TP11.1, U10.39 (GPIO1/TOUCH1/ADC1_CH0)
/CAM.D2: J6.6, U10.7 (GPIO7/TOUCH7/ADC1_CH6)
/CAM.D3: J6.4, U10.5 (GPIO5/TOUCH5/ADC1_CH4)
/CAM.D4: J6.3, U10.4 (GPIO4/TOUCH4/ADC1_CH3)
/CAM.D5: J6.5, U10.6 (GPIO6/TOUCH6/ADC1_CH5)
/CAM.D6: J6.7, U10.8 (GPIO15/U0RTS/ADC2_CH4/XTAL_32K_P)
/CAM.D7: J6.9, U10.10 (GPIO17/U1TXD/ADC2_CH6)
/CAM.D8: J6.11, U10.11 (GPIO18/U1RXD/ADC2_CH7/CLK_OUT3)
/CAM.D9: J6.13, U10.20 (GPIO12/TOUCH12/ADC2_CH1/FSPICLK/FSPIIO6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)
/CAM.HREF: J6.16, U10.33 (MTDO/GPIO40/CLK_OUT2)
/CAM.MCLK: J6.12, U10.12 (GPIO8/TOUCH8/ADC1_CH7/SUBSPICS1)
/CAM.PCLK: C48.1, J6.8, U10.9 (GPIO16/U0CTS/ADC2_CH5/XTAL_32K_NH5)
/CAM.PWDN: J6.17, U10.17 (GPIO9/TOUCH9/ADC1_CH8/FSPIHD/SUBSPIHD)
/CAM.RST: J6.19, U10.19 (GPIO11/TOUCH11/ADC2_CH0/FSPID/FSPIIO5/S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)
/CAM.SCL: J4.11, J6.20, Q1.2 (S), R29.2, U10.15 (GPIO3/TOUCH3/ADC1_CH2), U12.4 (SCL)
/CAM.SDA: J4.13, J6.22, Q2.2 (S), R30.2, U10.21 (GPIO13/TOUCH13/ADC2_CH2/FSPIQ/FSPIIO7/S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), U12.6 (SDA)
/CAM.VSYNC: J6.18, U10.18 (GPIO10/TOUCH10/ADC1_CH9/FSPICS0/FSPIIO4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)
/ESP_BOOT: C21.2, J3.6, J4.5, R26.1, SW2.2, TP2.1, U10.27 (GPIO0/BOOT)
/ESP_EN: C22.2, J3.5, J4.3, R27.1, SW3.2, TP1.1, U10.3 (EN)
/IO38: J4.15, U10.31 (GPIO38/FSPIWP/SUBSPIWP)
/IO39: J4.17, U10.32 (MTCK/GPIO39/CLK_OUT3/SUBSPICS1)
/IRCUT_CTRL: R31.2, TP10.1, U9.3 (FBC), U10.25 (GPIO48/SPICLK_N/SUBSPICLK_N_DIFF)
/IRLED_PWM: R32.2, TP14.1, U10.16 (GPIO46), U11.4 (EN)
/PIR_CTRL_D: R15.2, TP8.1, U4.3 (D), U10.23 (GPIO21)
/PIR_CTRL_LE: R16.2, TP7.1, U4.1 (LE), U10.26 (GPIO45)
/PIR_OUT: Q10.3 (D), U10.24 (GPIO47/SPICLK_P/SUBSPICLK_P_DIFF)
/PWRON_DET: Q9.1 (G), R22.2, SW1.2, U10.38 (GPIO2/TOUCH2/ADC1_CH1)
/PWR_EN: Q7.1 (G), R19.2, TP12.1, U10.22 (GPIO14/TOUCH14/ADC2_CH3/FSPIWP/FSPIDQS/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)
/PWR_PIR: C7.1, C10.1, C16.1, R20.1, SW1.1, TP13.1, U2.2 (VO), U4.5 (VCC), U6.1 (VDD)
/RXD0: J3.8, J4.9, TP5.1, U10.36 (U0RXD/GPIO44/CLK_OUT2)
/TXD0: J3.7, J4.7, TP4.1, U10.37 (U0TXD/GPIO43/CLK_OUT1)
/UD+: D4.2 (A2), J2.A6 (D+), J2.B6 (D+), U10.14 (GPIO20/U1CTS/ADC2_CH9/CLK_OUT1/USB_D+)
/UD-: D3.2 (A2), J2.A7 (D-), J2.B7 (D-), U10.13 (GPIO19/U1RTS/ADC2_CH8/CLK_OUT2/USB_D-)
/USR_BTN: C23.2, SW4.2, U10.34 (MTDI/GPIO41/CLK_OUT1)
/USR_LED: R28.1, U10.35 (MTMS/GPIO42)
GND: C1.2, C2.1, C3.1, C4.1, C5.2, C6.2, C7.2, C9.1, C10.2, C11.2, C12.2, C13.1, C14.2, C15.1, C16.2, C18.1, C19.1, C20.1, C21.1, C22.1, C23.1, C24.1, C25.2, C26.2, C27.2, C28.2, C29.2, C30.2, C31.2, C32.2, C33.1, C34.1, C35.2, C36.2, C37.1, C38.2, C39.2, C40.2, C41.1, C42.2, C43.2, C44.2, C45.1, C46.2, C47.2, C48.2, C49.2, C50.1, C51.1, C52.1, C53.2, C54.1, C55.2, C56.1, C57.1, D3.1 (A1), D4.1 (A1), D5.1 (A1), D7.1 (K), J1.1, J2.A1 (GND), J2.A12 (GND), J2.B1 (GND), J2.B12 (GND), J3.3, J3.4, J4.4, J4.6, J4.8, J4.10, J4.12, J4.14, J4.16, J4.18, J4.19, J4.20, J6.10, J6.23, Q5.2 (S), Q7.2 (S), Q9.2 (S), Q10.2 (S), R2.2, R3.2, R8.2, R9.2, R10.2, R11.2, R12.2, R13.2, R15.1, R16.1, R17.1, R19.1, R21.2, R22.1, R24.2, R25.1, R31.1, R32.1, R33.2, SW2.1, SW3.1, SW4.1, TP3.1, TP6.1, TP9.1, TP15.1, TP17.1, TP20.1, TP24.1, U1.2 (GND), U2.1 (GND), U3.4 (VSS), U4.2 (G), U4.6 (~OE), U5.2 (GND), U6.3 (VSS), U7.1 (GND), U8.1 (GND), U9.2 (GND), U10.1 (GND), U10.40 (GND), U10.41 (GND), U11.2 (GND), U12.3 (GND)
GNDPWR: C2.2, H1.1, H2.1, H3.1, H4.1, J2.S1 (SHIELD), R3.1
unnamed: D1.2 (A), R4.2
unnamed: D1.1 (K), U1.1 (~CHRG)
unnamed: D2.2 (A), R5.2
unnamed: D2.1 (K), U1.5 (~STDBY)
unnamed: D6.2 (A), JP1.1 (A), R14.1
unnamed: D7.2 (A), R28.2
unnamed: D8.2 (A), L5.2, U11.1 (SW)
unnamed: C49.1, C50.2, C51.2, C52.2, D8.1 (K), D9.2 (A), U11.5 (OV)
unnamed: D10.2 (A), D12.1 (K)
unnamed: D10.1 (K), R33.1, U11.3 (FB)
unnamed: D9.1 (K), D11.2 (A)
unnamed: D11.1 (K), D13.2 (A)
unnamed: D12.2 (A), D14.1 (K)
unnamed: D13.1 (K), D15.2 (A)
unnamed: D14.2 (A), D16.1 (K)
unnamed: D15.1 (K), D17.2 (A)
unnamed: D16.2 (A), D18.1 (K)
unnamed: D17.1 (K), D18.2 (A)
unnamed: J2.A5 (CC1), R8.1
unnamed: J2.B5 (CC2), R9.1
unnamed: J2.A4 (VBUS), J2.A9 (VBUS), J2.B4 (VBUS), J2.B9 (VBUS), L1.1
unnamed: J5.1, U9.6 (OUT2)
unnamed: J5.2, U9.4 (OUT1)
unnamed: JP2.1 (A), Q8.3 (D), Q10.1 (G), R25.2
unnamed: JP2.2 (B), Q5.1 (G), R17.2
unnamed: Q1.3 (D), R6.2, U3.6 (SCL)
unnamed: Q2.3 (D), R7.2, U3.5 (SDA)
unnamed: C8.1, Q3.1 (G), Q4.1 (G), R13.1, R14.2
unnamed: C8.2, Q3.2 (S), Q4.2 (S)
unnamed: Q5.3 (D), Q6.1 (G), Q7.3 (D), Q9.3 (D), R18.2, U3.3 (~INT)
unnamed: Q6.3 (D), R21.1, U5.1 (EN)
unnamed: C11.1, C12.1, C13.2, C14.1, C15.2, L2.2, Q6.2 (S), R18.1, U5.4 (IN)
unnamed: Q8.1 (G), R20.2, U4.4 (Q)
unnamed: Q8.2 (S), U6.2 (REL)
unnamed: R11.1, R12.1, U1.6 (PROG)
unnamed: U3.1 (OSCI), Y1.2
unnamed: U3.2 (OSCO), Y1.1
unnamed: C17.2, R23.2, R24.1, U5.5 (FB)
unnamed: L3.1, U5.3 (LX)
unnamed: C27.1, C30.1, C31.1, L4.2, U7.3 (VI), U8.3 (VI)
unnamed: C28.1, C29.1, U9.1 (CE)
VBUS: C4.2, C6.1, C9.2, C41.2, C43.1, C45.2, D6.1 (K), J3.1, J4.2, L2.1, L5.1, Q4.3 (D), R6.1, R7.1, TP21.1, U2.3 (VI), U3.8 (VDD), U11.6 (VIN)

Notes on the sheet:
Found in AI-Thinker design, purpose is yet to be understood
External MAXLAB ESP32 programmer can be used to flash and interact with the camera via the TagConnect cable
I_{led} = [ V_{fb} = 94mV <->114mV ] / [ ~2.4R ] ~= 40mA
But it is better not to go any higher than 1M in divider resistors, since the output impedance of a divider will be significant enough to interplay with input ADC impedance of the MCU
Pulling both inputs to 0 latches the state of the D-latch
Note: 3v3 and 5v are used as an output here to power the external programmer UART buffers. Internal programmer LDO output must be disabled then
Layout: Put IRCUT driver away from sensitive digital or analog lines
Layout: form a loop of GNDPWR around the PCB Do a via stitching with a spacing <= 20mm (resonant freq of the via cell is ~15 GHz)
Pull-down is included for CAM.RST and CAM.PWDN internally.
TODO: write comments about IO3, IO46, IO45 strappping pins
Bus connections to ESP32 MCU are optimized for easier layout
To prevent USB from powering VBUS completely, just in case
PWR_ON button starts DC-DC. MCU is responsible then for taking over PWR_EN signal The NMOS here is merely to make sure a signal polarity matches logical states (ON is HIGH>0V, OFF is LOW=0V) added benefit is that we no longer need OD MCU output on PWR_EN
Power Down Mode datasheet quote: To initiate hardware power-down, the PWDN pin (pin B6) must be tied to high. When this occurs, the OV2640 internal device clock is halted and all internal counters are reset. The current draw is less than 15 µA in this standby mode
Layout: Put LDOs as close as possible to the camera connector Keep separate "island" for camera connector and LDOs there
TODO: decide if sophisticated AGND connection (layout) is required for camera connector
5K PROG sets charging current to 200 mA
Given OV2640 sensitivity, an optimal LED should be C396643 @ LCSC (I_{max} ~40ma for T <= 60C, f_{peak} = 850nm, MPN: E6C0603IRAC1UDA) Forward drop should be in a region of ~1.6V The driver is capable of driving 7 white LEDs. WLED forward drop should be in the vicinity of ~3V. Meaning, that, hypote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
BATT_DETECT connected straight to the MCU, despite during the power-down condition they might supply some phantom current The hope is that output divider impedance is high enough for the phantom current to be low enough to cause any issue
Dedicated power supply to support the PIR wakeup when main DC-DC is turned off
Projected voltage: ~16V
Layout: Decoupling: keep as close to the camera connector as possible

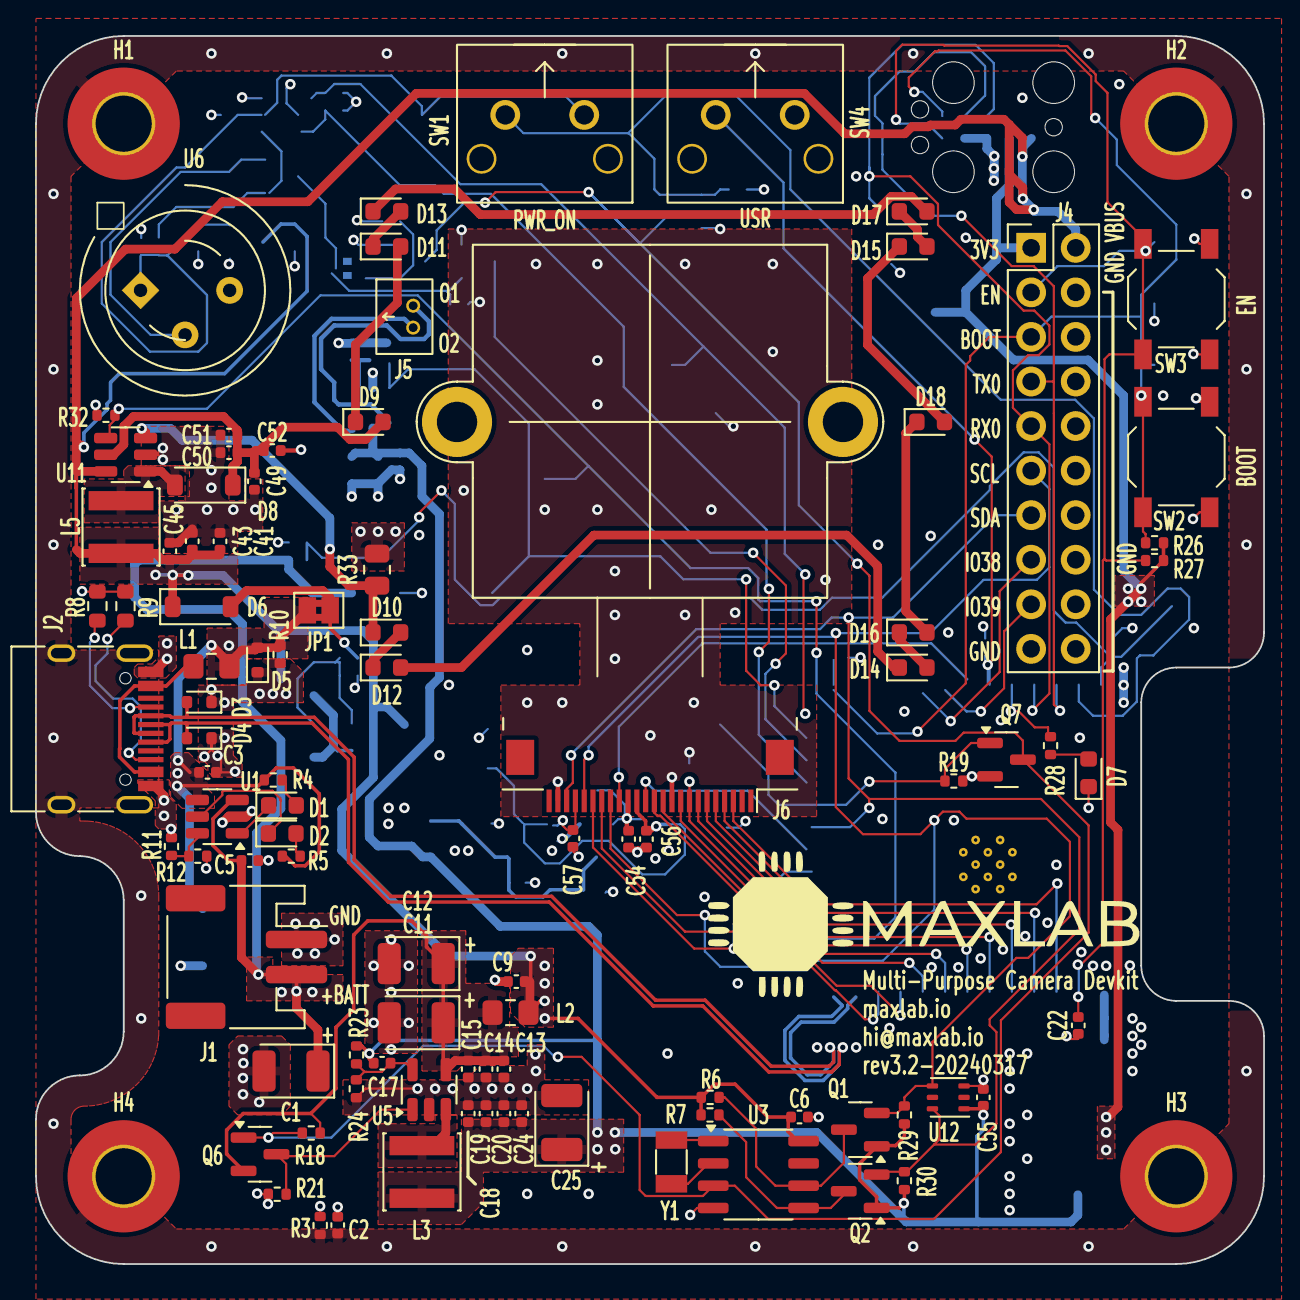
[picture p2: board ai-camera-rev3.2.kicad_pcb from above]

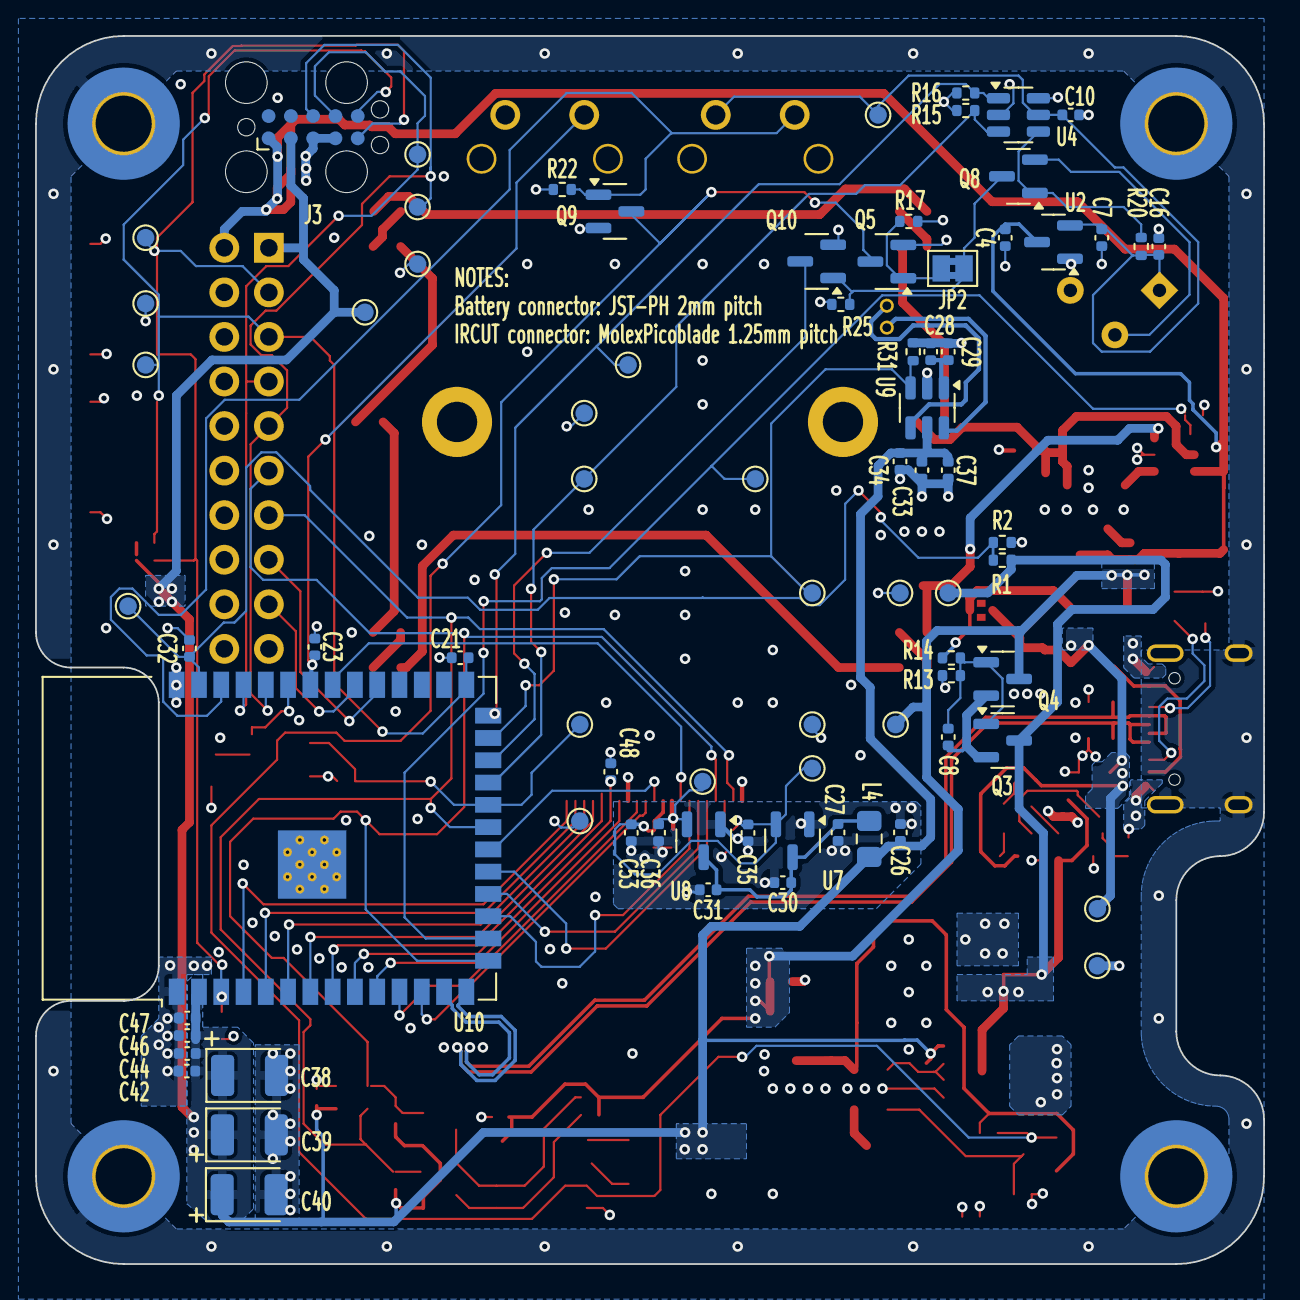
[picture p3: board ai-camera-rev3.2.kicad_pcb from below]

Board: 4 copper layers, 70.0 x 70.0 mm, 176 parts (78 on the bottom side), 84 nets.

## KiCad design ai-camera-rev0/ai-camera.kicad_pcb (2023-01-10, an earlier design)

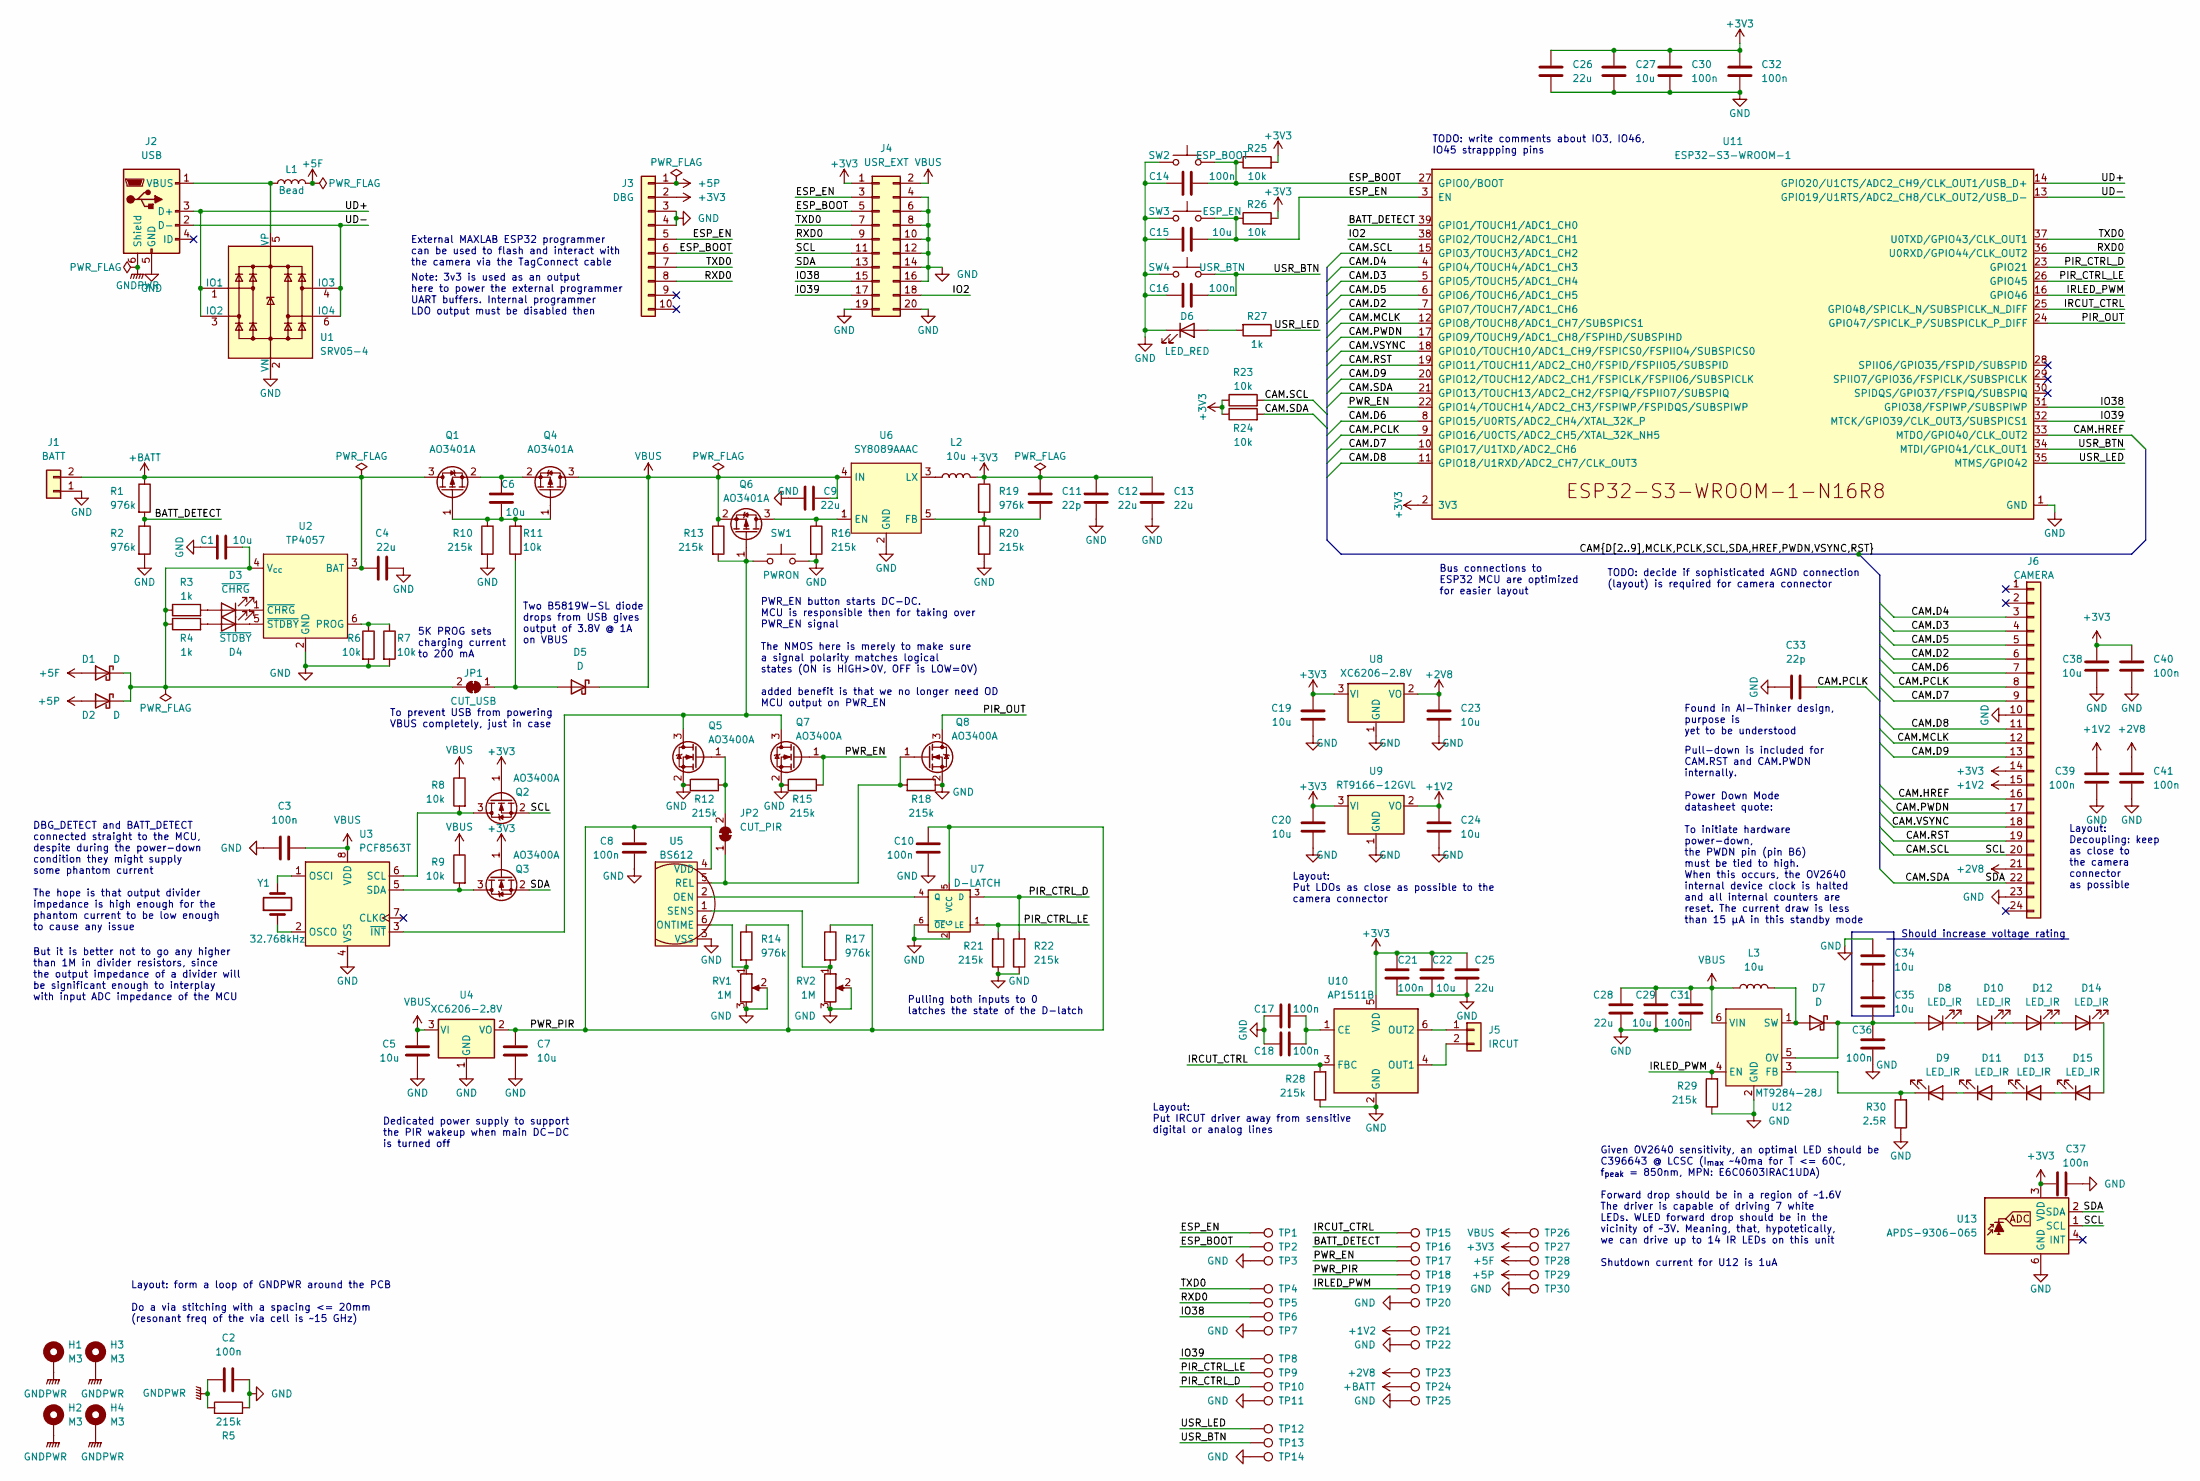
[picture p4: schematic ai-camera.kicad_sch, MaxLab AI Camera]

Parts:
C1, C5, C6, C7, C15, C19, C20, C22, C23, C24, C27, C29, C34, C35, C38: 10u_0603_CL10A106MA8NRNC; C_0603_1608Metric; Rating 25V; Tolerance 20%; MPN CL10A106MA8NRNC
C2, C3, C8, C10, C14, C16, C17, C18, C21, C30, C31, C32, C36, C37, C39, C40, C41: 100n_0402_CL05B104KB54PNC; C_0402_1005Metric; Tolerance 10%; Rating 50V; MPN CL05B104KB54PNC
C4, C9, C12, C13, C25, C26, C28: 22u_0805_CL21A226MAQNNNE; C_0805_2012Metric; Rating 10V; Tolerance 20%; MPN CL21A226MAQNNNE
C11, C33: 22p_0402_0402CG220J500NT; C_0402_1005Metric; Rating 50V; Tolerance 5%; MPN 0402CG220J500NT
D1, D2, D5, D7: B5819W-SL_SOD-123; D_SOD-123; MPN B5819W SL
D3, D6: 0603_RED_KT-0603R; LED_0603_1608Metric; MPN KT-0603R
D4: 0603_GREEN_19-217/GHC-YR1S2/3T; LED_0603_1608Metric; MPN 19-217/GHC-YR1S2/3T
D8, D9, D10, D11, D12, D13, D14, D15: 0603_IR_850nm_E6C0603IRAC1UDA; LED_0603_1608Metric; MPN E6C0603IRAC1UDA
H1, H2, H3, H4: M3; MountingHole_3.2mm_M3_DIN965_Pad_TopBottom
J1: Conn-01x02_P2mm_NONAME_JST-PH_C47647; JST_PH_S2B-PH-SM4-TB_1x02-1MP_P2.00mm_Horizontal; MPN C47647
J2: USB_B_Micro_10118194-0001LF; USB_Micro-B_Amphenol_10118194_Horizontal; MPN 10118194-0001LF
J3: DBG; Tag-Connect_TC2050-IDC-NL_2x05_P1.27mm_Vertical
J4: Conn-02x10_P2.54mm_B-2100S20P-B110; PinHeader_2x10_P2.54mm_Vertical; MPN B-2100S20P-B110
J5: Conn-01x02_P1.25mm_10114829-10102LF; 10114829-10102LF; MPN 10114829-10102LF
J6: Conn_01x24_FFC_0.5mm_hirose_FH12-24S-0.5SH; Hirose_FH12-24S-0.5SH_1x24-1MP_P0.50mm_Horizontal; MPN FH12-24S-0.5SH
JP1: CUT_USB; SolderJumper-2_P1.3mm_Bridged_RoundedPad1.0x1.5mm
JP2: CUT_PIR; SolderJumper-2_P1.3mm_Bridged_RoundedPad1.0x1.5mm
L1: 0805_FB_220R@100MHz_BLM21PG221SN1D; L_0805_2012Metric_Pad1.15x1.40mm_HandSolder; Rating 2A; MPN BLM21PG221SN1D
L2, L3: 10u_SWPA4030S100MT; L_Sunlord_SWPA40xxS; Rating 1.5A; MPN SWPA4030S100MT
Q1, Q4, Q6: AO3401A; SOT-23; MPN AO3401A
Q2, Q3, Q5, Q7, Q8: AO3400A; SOT-23; MPN AO3400A
R1, R2, R14, R17, R19: 976k_0402_0402WGD9763TCE; R_0402_1005Metric; Tolerance 0.5%; MPN 0402WGD9763TCE
R3, R4, R27: 1k_0402_0402WGF1001TCE; R_0402_1005Metric; Tolerance 1%; MPN 0402WGF1001TCE
R5, R10, R12, R13, R15, R16, R18, R20, R21, R22, R28, R29: 215k_0402_0402WGD2153TCE; R_0402_1005Metric; Tolerance 0.5%; MPN 0402WGD2153TCE
R6, R7, R8, R9, R11, R23, R24, R25, R26: 10k_0402_0402WGF1002TCE; R_0402_1005Metric; Tolerance 1%; MPN 0402WGF1002TCE
R30: 2.5R_0805_AR05FTCW2R50; R_0805_2012Metric; Tolerance 1%; MPN AR05FTCW2R50
RV1, RV2: 1M_3362P-1-105; Potentiometer_Vishay_T73YP_Vertical; Tolerance 10%; MPN 3362P-1-105
SW1, SW4: SW_PB_90deg_K2-1102AQ-H4CW-01; MPN K2-1102AQ-H4CW-01
SW2, SW3: SW_PB_TS-1187A-B-A-B; SW_SPST_TL3342; MPN TS-1187A-B-A-B
TP1, TP2, TP3, TP4, TP5, TP6, TP7, TP8, TP9, TP10, TP11, TP12, TP13, TP14, TP15, TP16, TP17, TP18, TP19, TP20, TP21, TP22, TP23, TP24, TP25, TP26, TP27, TP28, TP29, TP30: TP; TestPoint_Pad_D1.5mm
U1: SRV05-4; SOT-23-6; MPN SRV05-4
U2: TP4057-42-SOT26-R; SOT-23-6; MPN TP4057-42-SOT26-R
U3: PCF8563T/5,518; SOIC-8_3.9x4.9mm_P1.27mm; MPN PCF8563T/5,518
U4, U8: XC6206-2.8V; SOT-23; MPN XC6206-2.8V
U5: PIR_BS612; BS612; MPN BS612
U6: SY8089AAAC; SOT-23-5; MPN SY8089AAAC
U7: SOT-23-6_SN74LVC1G373DBVR_TI; SOT-23-6; MPN SN74LVC1G373DBVR
U9: RT9166-12GVL; SOT-23; MPN RT9166-12GVL
U10: AP1511B; SOT-23-6; MPN AP1511B
U11: ESP32-S3-WROOM-1-N16R8; ESP32-S3-WROOM-1; MPN ESP32-S3-WROOM-1-N16R8
U12: MT9284-28J; SOT-23-6; MPN MT9284-28J
U13: APDS-9306-065; Broadcom_DFN-6_2x2mm_P0.65mm; MPN APDS-9306-065
Y1: 32.768kHz_Q13FC1350000400; Crystal_SMD_3215-2Pin_3.2x1.5mm; MPN Q13FC1350000400

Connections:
+1V2: C24.1, C39.2, J6.15, TP21.1, U9.2 (VO)
+2V8: C23.1, C41.2, J6.21, TP23.1, U8.2 (VO)
+3V3: C11.1, C12.1, C13.1, C19.1, C20.1, C21.2, C22.2, C25.2, C26.1, C27.1, C30.1, C32.1, C37.1, C38.1, C40.2, J3.2, J4.1, J6.14, L2.2, Q2.1 (G), Q3.1 (G), R19.1, R23.1, R24.1, R25.2, R26.2, TP27.1, U8.3 (VI), U9.3 (VI), U10.5 (VDD), U11.2 (3V3), U13.3 (VDD)
+5F: D1.2 (A), L1.2, TP28.1
+5P: D2.2 (A), J3.1, TP29.1
+BATT: C4.1, J1.2, Q1.3 (D), R1.1, TP24.1, U2.3 (BAT)
/BATT_DETECT: R1.2, R2.1, TP16.1, U11.39 (GPIO1/TOUCH1/ADC1_CH0)
/CAM.D2: J6.6, U11.7 (GPIO7/TOUCH7/ADC1_CH6)
/CAM.D3: J6.4, U11.5 (GPIO5/TOUCH5/ADC1_CH4)
/CAM.D4: J6.3, U11.4 (GPIO4/TOUCH4/ADC1_CH3)
/CAM.D5: J6.5, U11.6 (GPIO6/TOUCH6/ADC1_CH5)
/CAM.D6: J6.7, U11.8 (GPIO15/U0RTS/ADC2_CH4/XTAL_32K_P)
/CAM.D7: J6.9, U11.10 (GPIO17/U1TXD/ADC2_CH6)
/CAM.D8: J6.11, U11.11 (GPIO18/U1RXD/ADC2_CH7/CLK_OUT3)
/CAM.D9: J6.13, U11.20 (GPIO12/TOUCH12/ADC2_CH1/FSPICLK/FSPIIO6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)
/CAM.HREF: J6.16, U11.33 (MTDO/GPIO40/CLK_OUT2)
/CAM.MCLK: J6.12, U11.12 (GPIO8/TOUCH8/ADC1_CH7/SUBSPICS1)
/CAM.PCLK: C33.1, J6.8, U11.9 (GPIO16/U0CTS/ADC2_CH5/XTAL_32K_NH5)
/CAM.PWDN: J6.17, U11.17 (GPIO9/TOUCH9/ADC1_CH8/FSPIHD/SUBSPIHD)
/CAM.RST: J6.19, U11.19 (GPIO11/TOUCH11/ADC2_CH0/FSPID/FSPIIO5/S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)
/CAM.SCL: J4.11, J6.20, Q2.2 (S), R23.2, U11.15 (GPIO3/TOUCH3/ADC1_CH2), U13.1 (SCL)
/CAM.SDA: J4.13, J6.22, Q3.2 (S), R24.2, U11.21 (GPIO13/TOUCH13/ADC2_CH2/FSPIQ/FSPIIO7/S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), U13.2 (SDA)
/CAM.VSYNC: J6.18, U11.18 (GPIO10/TOUCH10/ADC1_CH9/FSPICS0/FSPIIO4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)
/ESP_BOOT: C14.2, J3.6, J4.5, R25.1, SW2.2, TP2.1, U11.27 (GPIO0/BOOT)
/ESP_EN: C15.2, J3.5, J4.3, R26.1, SW3.2, TP1.1, U11.3 (EN)
/IO2: J4.18, U11.38 (GPIO2/TOUCH2/ADC1_CH1)
/IO38: J4.15, TP6.1, U11.31 (GPIO38/FSPIWP/SUBSPIWP)
/IO39: J4.17, TP8.1, U11.32 (MTCK/GPIO39/CLK_OUT3/SUBSPICS1)
/IRCUT_CTRL: R28.2, TP15.1, U10.3 (FBC), U11.25 (GPIO48/SPICLK_N/SUBSPICLK_N_DIFF)
/IRLED_PWM: R29.2, TP19.1, U11.16 (GPIO46), U12.4 (EN)
/PIR_CTRL_D: R22.2, TP10.1, U7.3 (D), U11.23 (GPIO21)
/PIR_CTRL_LE: R21.2, TP9.1, U7.1 (LE), U11.26 (GPIO45)
/PIR_OUT: Q8.3 (D), U11.24 (GPIO47/SPICLK_P/SUBSPICLK_P_DIFF)
/PWR_EN: Q7.1 (G), R15.2, TP17.1, U11.22 (GPIO14/TOUCH14/ADC2_CH3/FSPIWP/FSPIDQS/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)
/PWR_PIR: C7.1, C8.1, C10.1, R14.1, R17.1, TP18.1, U4.2 (VO), U5.4 (VDD), U7.5 (VCC)
/RXD0: J3.8, J4.9, TP5.1, U11.36 (U0RXD/GPIO44/CLK_OUT2)
/TXD0: J3.7, J4.7, TP4.1, U11.37 (U0TXD/GPIO43/CLK_OUT1)
/UD+: J2.3 (D+), U1.1 (IO1), U1.3 (IO2), U11.14 (GPIO20/U1CTS/ADC2_CH9/CLK_OUT1/USB_D+)
/UD-: J2.2 (D-), U1.4 (IO3), U1.6 (IO4), U11.13 (GPIO19/U1RTS/ADC2_CH8/CLK_OUT2/USB_D-)
/USR_BTN: C16.2, SW4.2, TP13.1, U11.34 (MTDI/GPIO41/CLK_OUT1)
/USR_LED: R27.1, TP12.1, U11.35 (MTMS/GPIO42)
GND: C1.1, C2.1, C3.2, C4.2, C5.1, C7.2, C8.2, C9.2, C10.2, C12.2, C13.2, C14.1, C15.1, C16.1, C17.2, C18.2, C19.2, C20.2, C21.1, C22.1, C23.2, C24.2, C25.1, C26.2, C27.2, C28.1, C29.1, C30.2, C31.1, C32.2, C33.2, C34.1, C36.1, C37.2, C38.2, C39.1, C40.1, C41.1, D6.1 (K), J1.1, J2.5 (GND), J3.3, J3.4, J4.4, J4.6, J4.8, J4.10, J4.12, J4.14, J4.16, J4.19, J4.20, J6.10, J6.23, Q5.2 (S), Q7.2 (S), Q8.2 (S), R2.2, R5.2, R6.2, R7.2, R10.2, R12.1, R15.1, R16.2, R18.1, R20.2, R21.1, R22.1, R28.1, R29.1, R30.1, RV1.2, RV1.3, RV2.2, RV2.3, SW1.2, SW2.1, SW3.1, SW4.1, TP3.1, TP7.1, TP11.1, TP14.1, TP20.1, TP22.1, TP25.1, TP30.1, U1.2 (VN), U2.2 (GND), U3.4 (VSS), U4.1 (GND), U5.3 (VSS), U6.2 (GND), U7.2 (G), U7.6 (~OE), U8.1 (GND), U9.1 (GND), U10.2 (GND), U11.1 (GND), U11.40 (GND), U11.41 (GND), U12.2 (GND), U13.6 (GND)
GNDPWR: C2.2, H1.1, H2.1, H3.1, H4.1, J2.6 (Shield), R5.1
unnamed: C1.2, D1.1 (K), D2.1 (K), JP1.2 (B), R3.1, R4.1, U2.4 (V_{cc})
unnamed: C6.1, Q1.1 (G), Q4.1 (G), R10.1, R11.2
unnamed: C6.2, Q1.2 (S), Q4.2 (S)
unnamed: C11.2, R19.2, R20.1, U6.5 (FB)
unnamed: C17.1, C18.1, U10.1 (CE)
unnamed: C34.2, C35.2
unnamed: C35.1, C36.2, D7.1 (K), D8.2 (A), U12.5 (OV)
unnamed: D3.1 (K), U2.1 (~CHRG)
unnamed: D3.2 (A), R3.2
unnamed: D4.1 (K), U2.5 (~STDBY)
unnamed: D4.2 (A), R4.2
unnamed: D5.2 (A), JP1.1 (A), R11.1
unnamed: D6.2 (A), R27.2
unnamed: D7.2 (A), L3.2, U12.1 (SW)
unnamed: D9.1 (K), R30.2, U12.3 (FB)
unnamed: D10.1 (K), D12.2 (A)
unnamed: D8.1 (K), D10.2 (A)
unnamed: D9.2 (A), D11.1 (K)
unnamed: D11.2 (A), D13.1 (K)
unnamed: D12.1 (K), D14.2 (A)
unnamed: D13.2 (A), D15.1 (K)
unnamed: D14.1 (K), D15.2 (A)
unnamed: J2.1 (VBUS), L1.1, U1.5 (VP)
unnamed: J5.1, U10.6 (OUT2)
unnamed: J5.2, U10.4 (OUT1)
unnamed: JP2.1 (A), Q8.1 (G), R18.2, U5.5 (REL)
unnamed: JP2.2 (B), Q5.1 (G), R12.2
unnamed: L2.1, U6.3 (LX)
unnamed: Q2.3 (D), R8.2, U3.6 (SCL)
unnamed: Q3.3 (D), R9.2, U3.5 (SDA)
unnamed: Q5.3 (D), Q6.1 (G), Q7.3 (D), R13.2, SW1.1, U3.3 (~INT)
unnamed: Q6.3 (D), R16.1, U6.1 (EN)
unnamed: R6.1, R7.1, U2.6 (PROG)
unnamed: R14.2, RV1.1, U5.6 (ONTIME)
unnamed: R17.2, RV2.1, U5.1 (SENS)
unnamed: U3.1 (OSCI), Y1.2
unnamed: U3.2 (OSCO), Y1.1
unnamed: U5.2 (OEN), U7.4 (Q)
VBUS: C3.1, C5.2, C9.1, C28.2, C29.2, C31.2, D5.1 (K), J4.2, L3.1, Q4.3 (D), Q6.2 (S), R8.1, R9.1, R13.1, TP26.1, U3.8 (VDD), U4.3 (VI), U6.4 (IN), U12.6 (VIN)

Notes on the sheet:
Found in AI-Thinker design, purpose is yet to be understood
External MAXLAB ESP32 programmer can be used to flash and interact with the camera via the TagConnect cable
But it is better not to go any higher than 1M in divider resistors, since the output impedance of a divider will be significant enough to interplay with input ADC impedance of the MCU
Pulling both inputs to 0 latches the state of the D-latch
Note: 3v3 is used as an output here to power the external programmer UART buffers. Internal programmer LDO output must be disabled then
Layout: Put IRCUT driver away from sensitive digital or analog lines
Layout: form a loop of GNDPWR around the PCB Do a via stitching with a spacing <= 20mm (resonant freq of the via cell is ~15 GHz)
Pull-down is included for CAM.RST and CAM.PWDN internally.
Two B5819W-SL diode drops from USB gives output of 3.8V @ 1A on VBUS
Should increase voltage rating
TODO: write comments about IO3, IO46, IO45 strappping pins
Bus connections to ESP32 MCU are optimized for easier layout
To prevent USB from powering VBUS completely, just in case
PWR_EN button starts DC-DC. MCU is responsible then for taking over PWR_EN signal The NMOS here is merely to make sure a signal polarity matches logical states (ON is HIGH>0V, OFF is LOW=0V) added benefit is that we no longer need OD MCU output on PWR_EN
Power Down Mode datasheet quote: To initiate hardware power-down, the PWDN pin (pin B6) must be tied to high. When this occurs, the OV2640 internal device clock is halted and all internal counters are reset. The current draw is less than 15 µA in this standby mode
Layout: Put LDOs as close as possible to the camera connector
TODO: decide if sophisticated AGND connection (layout) is required for camera connector
5K PROG sets charging current to 200 mA
Given OV2640 sensitivity, an optimal LED should be C396643 @ LCSC (I_{max} ~40ma for T <= 60C, f_{peak} = 850nm, MPN: E6C0603IRAC1UDA) Forward drop should be in a region of ~1.6V The driver is capable of driving 7 white LEDs. WLED forward drop should be in the vicinity of ~3V. Meaning, that, hypote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
DBG_DETECT and BATT_DETECT connected straight to the MCU, despite during the power-down condition they might supply some phantom current The hope is that output divider impedance is high enough for the phantom current to be low enough to cause any issue
Dedicated power supply to support the PIR wakeup when main DC-DC is turned off
Layout: Decoupling: keep as close to the camera connector as possible

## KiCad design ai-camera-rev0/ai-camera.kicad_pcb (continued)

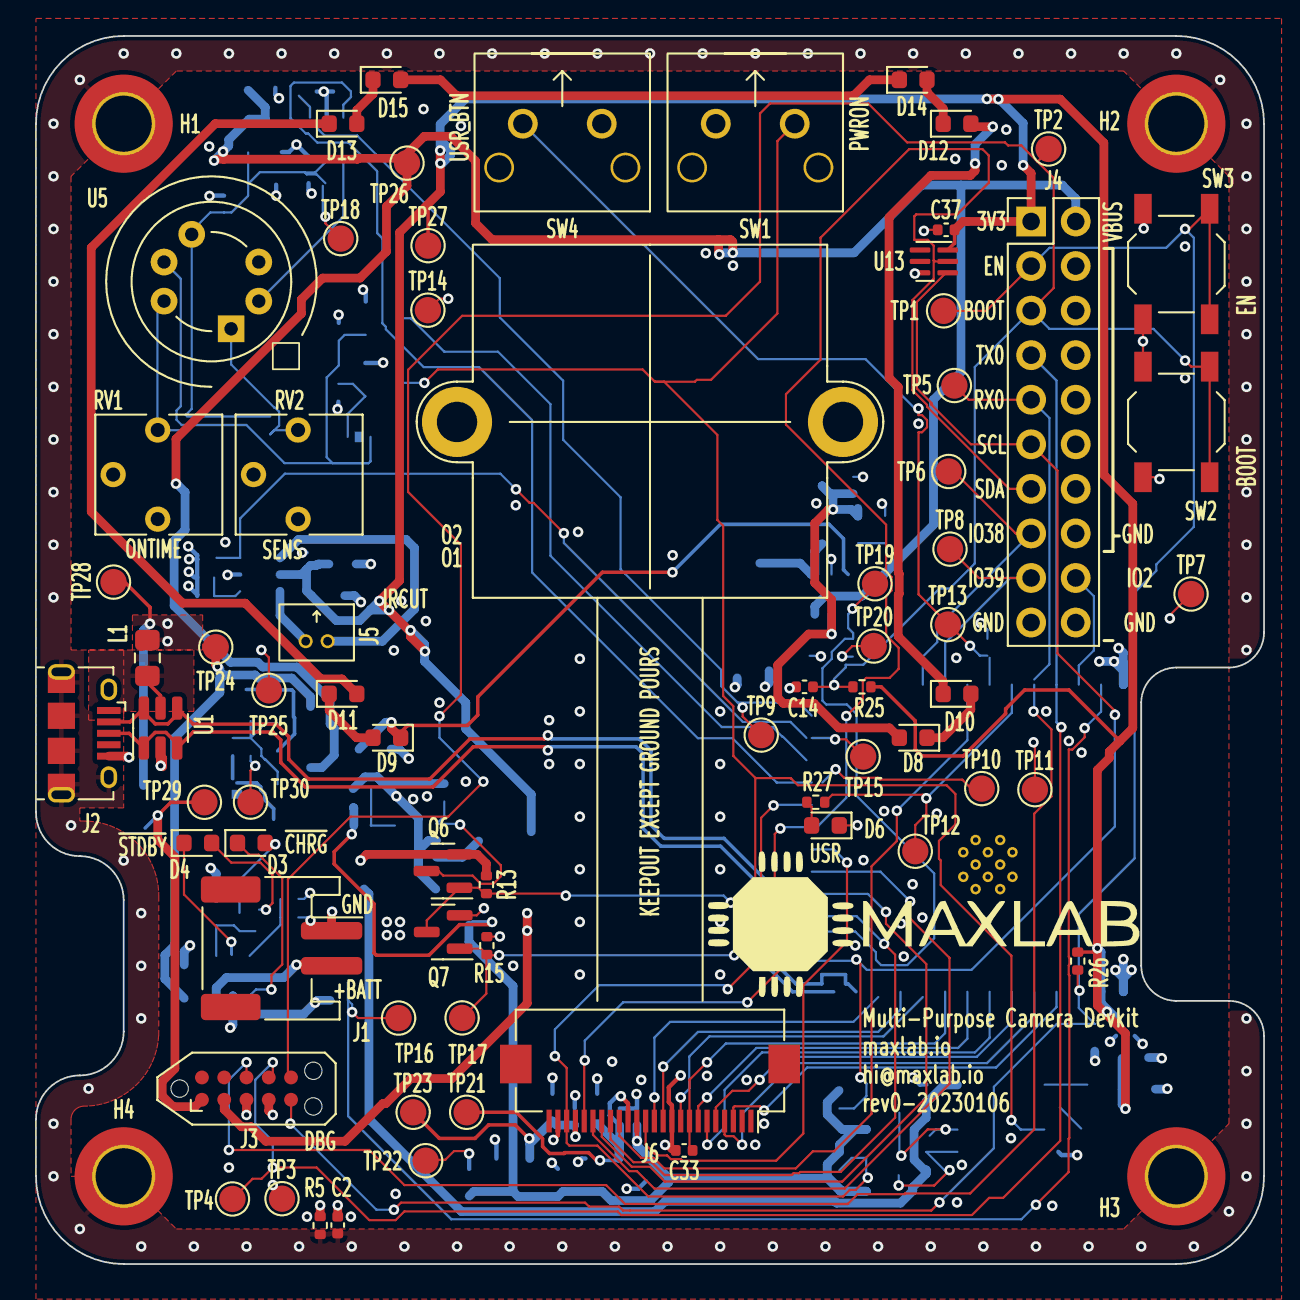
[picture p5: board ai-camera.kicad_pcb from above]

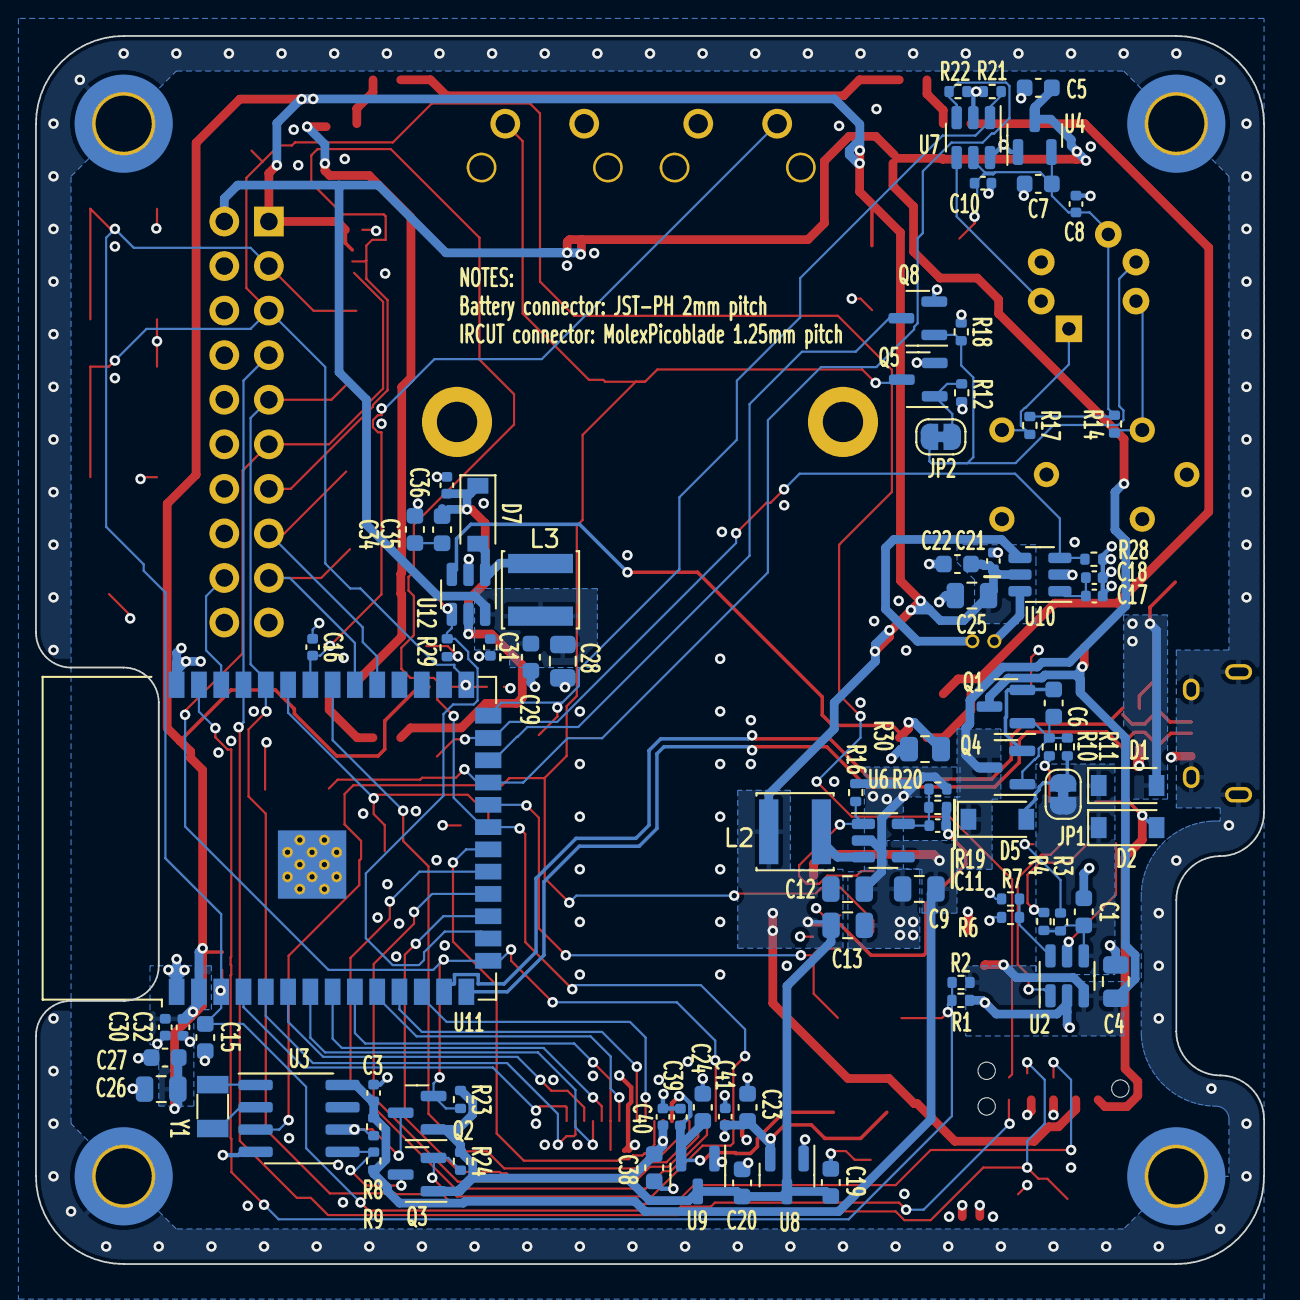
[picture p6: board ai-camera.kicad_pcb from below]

Board: 4 copper layers, 70.0 x 70.0 mm, 159 parts (86 on the bottom side), 82 nets.

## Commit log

2022-12-04 ai camera schematics part 1: draft components, except camera
    [ai-camera.kicad_sch]
2022-12-08 ai camera schematics part 2: debug and power distribution draft
    [ai-camera.kicad_sch]
2022-12-09 ai camera schematics part 3: PIR and PIR latch/control parts
    [ai-camera.kicad_sch]
2022-12-09 ai camera schematics part 3.1: add some comments
    [ai-camera.kicad_sch]
2022-12-14 ai camera schematics part 4: add camera bus and connector
    [ai-camera.kicad_sch]
2022-12-14 ai camera schematics part 5: add buffers to RX/TX
    [ai-camera.kicad_sch]
2022-12-14 ai camera schematics part 5.1: minor alignment
    [ai-camera.kicad_sch]
2022-12-17 ai camera schematics part 6: add LED driver, IRCUT, crystal, power switch for buffers
    [ai-camera.kicad_sch]
2022-12-18 ai camera schematics part 7: charger, LED feedback resistor, small fixes
    [ai-camera.kicad_sch]
2022-12-19 ai camera schematics part 8: use built-in USB support of ESP32 for flashing, fix DRC, footrpints and decoupling
    [ai-camera.kicad_sch]
2022-12-19 ai camera schematics part 9: USB shield connected
    [ai-camera.kicad_sch]
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2022-12-19 ai camera pcb part 1: missing 3d models addressed, prelim outline
    [ai-camera.kicad_pcb, ai-camera.kicad_sch]
2022-12-23 ai camera review 1: remove pull-up resistor for output latch (not necessary)
    [ai-camera.kicad_pcb, ai-camera.kicad_sch]
2022-12-23 ai camera review 2: fix the VBUS/USB/BATT power distribution
    Removing low-side NFET fixes the polarity. Now bidir FET switch is off
    when USB in plugged in (as it should). Additional diode prevents BATT
    propagating through the switch back to switch gates, forming a negative
    feedback. Additional solder jumper allow cutting USB power from the
    bidir switch and from VBUS completely
    [ai-camera.kicad_sch]
2022-12-23 ai camera review 3: move DBG_DETECT divider further along power path
    [ai-camera.kicad_sch]
2022-12-23 ai camera review 4: replace 10K with 215K to help reduce leakage in the ON state
    [ai-camera.kicad_sch]
2022-12-30 ai camera review 5: diversify selection of bypass caps
    [ai-camera.kicad_sch]
2022-12-30 ai camera review 6: separate sensor enable signal
    [ai-camera.kicad_sch]
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2022-12-31 ai camera review 7: remove redundant signals and address boostrapping and SPIFLASH pins allocations
    [ai-camera.kicad_sch]
2022-12-31 ai camera review 8: replace 1u/1206 with 10u/0603
    [ai-camera.kicad_pcb, ai-camera.kicad_sch]
2022-12-31 ai camera review 9: replace replace 1u/1206 with 10u/0603
    [ai-camera.kicad_pcb, ai-camera.kicad_sch]
2022-12-31 ai camera review 10: replace some 22u with 10u to save the board space
    [ai-camera.kicad_pcb, ai-camera.kicad_sch]
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2023-01-02 ai camera review 12: merge i2c buses together, free one additional line for user purposes
    [ai-camera.kicad_sch]
2023-01-02 ai camera review 13: use green LED for standby signal
    [ai-camera.kicad_sch]
2023-01-02 ai camera review 14: add aliases to CAM.SDA/SCL to confuse schematics less
    [ai-camera.kicad_pcb, ai-camera.kicad_sch]
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2023-01-04 ai camera layout: prelim USB, PIR, PIR cfg, battery, ML connector
    [ai-camera.kicad_pcb]
2023-01-04 ai camera review 15: add IR LEDs into the main schematics and fix lib warnings
    [ai-camera.kicad_sch]
2023-01-04 ai camera layout: prelim DC-DC, change inductors, IR placement
    [ai-camera.kicad_pcb, ai-camera.kicad_sch]
2023-01-04 ai camera layout: more LEDs, better caps to address LED driver voltage output
    [ai-camera.kicad_pcb, ai-camera.kicad_sch]
2023-01-05 ai camera layout: ALS selected and prelim component placement
    [ai-camera.kicad_pcb, ai-camera.kicad_sch]
2023-01-05 ai camera layout: route high speed camera and diffpair
    [ai-camera.kicad_pcb]
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2023-01-06 ai camera layout: battery and part of power circuit
    [ai-camera.kicad_pcb]
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2023-01-06 ai camera layout: route all signals and fix DRC
    [ai-camera.kicad_pcb, ai-camera.kicad_sch]
2023-01-06 ai camera layout: fix silkscreen and fab layers
    [ai-camera.kicad_pcb, ai-camera.kicad_sch]
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2023-01-06 ai camera layout: hide TP fab layer items
    [ai-camera.kicad_pcb]
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2023-01-06 ai camera layout: add logos and revision info
    [ai-camera.kicad_pcb]
2023-01-06 ai camera layout: fix 3d model for the inductor
    [ai-camera.kicad_pcb, ai-camera.kicad_sch]
2023-01-07 ai camera fab release: fix library links and MPNs for components
    [ai-camera.csv, ai-camera.kicad_sch]
2023-01-07 ai camera fab release: update PCB links to match schematics update
    [ai-camera.kicad_pcb]
2023-01-07 ai camera fab release: prelim bom, centroids, gerbs
    [ai-camera-B_Cu.gbl, ai-camera-B_Fab.gbr, ai-camera-B_Mask.gbs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]
2023-01-07 ai camera fab release: allow for camera sensor to have smaller FPC cable - move components out of the potential camera sensor position
    [ai-camera.kicad_pcb]
2023-01-07 ai camera fab release: opminize couple of traces, new gerbs in better format
    [ai-camera-B_Cu.gbl, ai-camera-B_Fab.gbr, ai-camera-B_Mask.gbs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]
2023-01-07 ai camera fab release: update gerbers with DRC warning fix
    [ai-camera-B_Cu.gbl, ai-camera-B_Fab.gbr, ai-camera-B_Mask.gbs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]
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2023-01-07 ai camera fab release: change color to black
    [ai-camera.kicad_pcb]
2023-01-10 ai camera fab release: replace batt connector - old one not in stock anymore
    [ai-camera.kicad_pcb, ai-camera.kicad_sch]
2023-01-10 ai camera fab release: add some PCB notes and battery connector silk
    [ai-camera.kicad_pcb]
2023-01-10 ai camera fab release: update gerbers with recent changes
    [ai-camera-B_Cu.gbl, ai-camera-B_Fab.gbr, ai-camera-B_Mask.gbs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]
2023-01-10 ai camera fab release: update bom and centroids to match JLCPCB standarts using JLCKicadTools script
    [ai-camera_bom_jlc.csv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]
2023-01-10 ai camera fab release: use proper BOM file name
    [ai-camera_bom_jlc.csv, bom.csv]
2023-02-12 EAC-23: BOM optimization: pots and FPC connector replaced with better alternative
    [ai-camera.kicad_pcb, ai-camera.kicad_sch]
2023-02-13 EAC-23: BOM optimization: replaced PIR and 2.5R with 2.43R bc better stock
    [ai-camera.kicad_sch]
2023-02-13 EAC-2: revisit capacitors to eliminate voltage dips and descrease noise
    additionally: add some filtering
    [ai-camera.csv, ai-camera.kicad_sch]
2023-02-14 EAC-2: begin layout: low impedance ground connections, move DC-DC farther away, USB-C to prevent dips
    [ai-camera.kicad_pcb, ai-camera.kicad_sch]
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2023-02-16 EAC-2: test points and DRC error fixes
    [ai-camera.kicad_pcb, ai-camera.kicad_sch]
2023-02-16 EAC-2: top silkscreen fix
    [ai-camera.kicad_pcb]
2023-02-16 EAC-2: bot silkscreen fix
    [ai-camera.kicad_pcb]
2023-02-16 EAC-2: use discrete TVSs to avoid backfeeding the 5V line when USB is off
    [ai-camera.kicad_pcb, ai-camera.kicad_sch]
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2023-02-17 EAC-23: use proper PCF RTC with good availability to count seconds
    [ai-camera.kicad_pcb, ai-camera.kicad_sch]
2023-02-17 EAC-23: replace N-MOS with 2N7002 and ALS with LTR-303ALS-01, since they're cheaper
    [ai-camera.csv, ai-camera.kicad_pcb, ai-camera.kicad_sch]
2023-02-17 EAC-23: update PCB and rev numbers to match recent changes
    [ai-camera.csv, ai-camera.kicad_sch]
2023-02-21 EAC-27: update crystal and USB with proper FPs & 3d models
    [ai-camera.kicad_pcb, ai-camera.kicad_sch]
2023-02-21 EAC-27: fix the fab layer
    [ai-camera.kicad_pcb]
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2023-03-16 EAC-49: move old revision files to separate dir to facilitate tracking
    [ai-camera-B_Cu.gbl, ai-camera-B_Fab.gbr, ai-camera-B_Mask.gbs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]
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2023-03-16 EAC-49: move ALS, PIR and improve power routing
    [ai-camera-rev2.kicad_pcb, ai-camera-rev2.kicad_sch]
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2023-03-18 EAC-49: update silkscreen and use single capacitor for all decoupling
    [ai-camera-rev2.kicad_pcb, ai-camera-rev2.kicad_sch]
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2023-03-18 EAC-49: add power-on detection in case of user button press
    [ai-camera-rev2.kicad_pcb, ai-camera-rev2.kicad_sch]
2023-03-18 EAC-49: fix battery labels
    [ai-camera-rev2.kicad_pcb]
2023-03-18 EAC-49: PWR_PIR instead of VBUS for PWRON button trigger
    [ai-camera-rev2.kicad_pcb, ai-camera-rev2.kicad_sch]
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2023-03-20 EAC-49: move camera connector to avoid FPC cable bending
    [ai-camera-rev2.kicad_pcb]
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2023-05-20 EAC-60: rev3: new set of files based on rev2
    [ai-camera-rev3.csv, ai-camera-rev3.kicad_pcb, ai-camera-rev3.kicad_sch]
2023-05-20 EAC-60: rev3: fix all errors and warnings from 7.0.2 KiCAD, update to newer KIML
    [ai-camera-rev3.kicad_pcb, ai-camera-rev3.kicad_sch]
2023-05-21 EAC-60: rev3: use proper buttons and update KIML reference
    [ai-camera-rev3.kicad_pcb, ai-camera-rev3.kicad_sch]
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2024-01-10 rev3.1: new revision to address noise
    [ai-camera-rev3.1.kicad_pcb, ai-camera-rev3.1.kicad_sch]
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
